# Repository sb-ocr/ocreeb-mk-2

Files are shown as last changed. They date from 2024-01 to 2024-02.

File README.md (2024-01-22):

# Ocreeb MK2: Modular Macro Keyboard System 

Watch the build video ↓

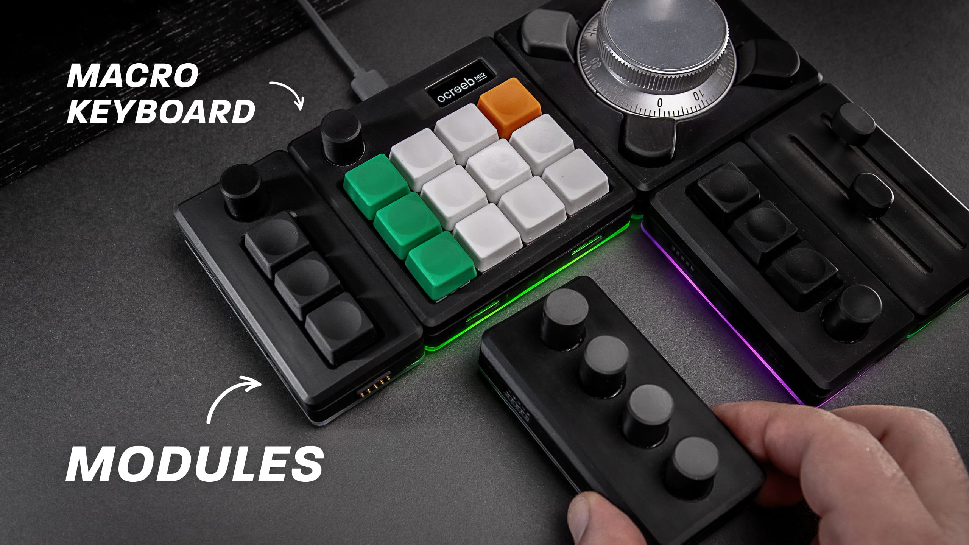
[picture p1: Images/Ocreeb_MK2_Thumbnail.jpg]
[](https://youtu.be/7DfexfHzT-w)

Ocreeb MK2 is the second iteration of my macropad project. This version features the XIAO RP2040, supports hotswap sockets for the macropad, a detachable switch plate, an OLED screen, and magnetic external modules running the Seesaw firmware.

As I mentioned in the video, there are still major performance issues when using multiple external modules. This is probably due to my implementation of the shared interrupt, and I will look into it. 
Nevertheless, I will supplement this repo with all the files in case you ever wish to use a part of this.

Build instructions → [Instructables](https://www.instructables.com/Modular-Macro-Keyboard-System-Ocreeb-MK2/)

[][cc-by-nc-sa]

[][cc-by-nc-sa]

[cc-by-nc-sa]: http://creativecommons.org/licenses/by-nc-sa/4.0/
[cc-by-nc-sa-image]: https://licensebuttons.net/l/by-nc-sa/4.0/88x31.png
[cc-by-nc-sa-shield]: https://img.shields.io/badge/License-CC%20BY--NC--SA%204.0-lightgrey.svg

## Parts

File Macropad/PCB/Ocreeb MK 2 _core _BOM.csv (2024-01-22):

Qty | Parts | Device | Value | Package | MP | Digikey | Type | Description | Link
1 | U1 | XIAO RP2040 |  |  | 102010428 | 1597-102010428-ND | SMD | RP2040 XIAO RP2040 - ARM® Cortex®-M0+ MCU 32-Bit
6 | C1, C2, C3, C4, C5, C6 | C_CHIP-0603(1608-METRIC) | 0.1uF | CAPC1608X85 | C0603C104M5RAC7867 | 399-C0603C104M5RAC7867CT-ND | SMD | 0.1 µF ±20% 50V Ceramic Capacitor X7R 0603 (1608 Metric)
5 | R1, R2, R3, R4, R5 | R-US_CHIP-0603(1608-METRIC) | 10K | RESC1608X60 | RMCF0603FT10K0 | RMCF0603FT10K0CT-ND | SMD | 10 kOhms ±1% 0.1W, 1/10W Chip Resistor 0603 (1608 Metric)
1 | F1 | PPTC_0.75A | 6V/0.75A | 1206 (3216 Metric) | PTS12066V075 | 283-PTS12066V075CT-ND | SMD | Polymeric PTC Resettable Fuse 6V 750 mA Ih Surface Mount 1206 (3216 Metric), Concave
2 | Q1, Q2 | BSS138 | BSS138 | SOT-23-3 | BSS138 | 4530-BSS138CT-ND | SMD | N-Channel 50 V 220mA (Ta) 350mW (Ta) Surface Mount SOT-23
4 | RN1, RN2, RN3, RN4 | CAY16-103J4LF | CAY16-103J4LF | 1206 (3216 Metric) | CAY16-103J4LF | CAY16-103J4LFCT-ND | SMD | 10k Ohm ±5% 62.5mW Power Per Element Isolated 4 Resistor Network/Array ±200ppm/°C 1206 (3216 Metric), Convex, Long Side Terminals
1 | U5 | SN74AHCT1G126DBVR | SN74AHCT1G126DBVR | SOT-23-5 | SN74AHCT1G126DBVR | 296-4710-1-ND | SMD | Buffer, Non-Inverting 1 Element 1 Bit per Element 3-State Output SOT-23-5
2 | U2, U3 | SN74HC165DBR16-TSSOP | SN74HC165DBR16-TSSOP | 16-SSOP | SN74HC165DBR | 296-23151-1-ND | SMD | Shift Shift Register 1 Element 8 Bit 16-SSOP
1 | U4 | TCA4307DGKR | TCA4307DGKR | 8-VSSOP | TCA4307DGKR | 296-TCA4307DGKRCT-ND | SMD | Hot Swap Controller 1 Channel General Purpose 8-VSSOP
4 | LED1, LED2, LED3, LED4 | WS2812B | WS2812B | WS2812B | COM-16347 | 1568-COM-16347CT-ND | SMD | Addressable Lighting - LED Serial NRZ (Shift Register) Red, Green, Blue (RGB)
1 | ENC | PEC11R-4215F-S0024 | PEC11R-4215F-S0024 | PEC11R-4215F-S0024 | PEC11R-4215F-S0024 | PEC11R-4215F-S0024-ND | TH | Rotary Encoder Mechanical 24 Quadrature (Incremental) Vertical
12 | S1, S2, S3, S4, S5, S6, S7, S8, S9, S10, S11, S12 | MX HOT SWAP SOCKETS |  | 20 Pack | 4958 | 1528-4958-ND | SMD | Kailh MX Hotswap Sockets
12 | S1, S2, S3, S4, S5, S6, S7, S8, S9, S10, S11, S12 | MX SWITCHES |  | 12 Pack | 5122 | 1528-5122-ND | TH | MX-Compatible Mechanical Keys
1 | OLED | OLED MODULE |  | 3 pcs |  |  | MOD | 0.91 inch OLED Display Module SSD1306 I2C 128x32 | https://geni.us/Jc6463D
6 | CONNECTOR | 5PIN_EDGE_LANDING |  | 5 pcs |  |  | SUB | Custom landing pads PCB | https://github.com/sb-ocr/ocreeb-mk-2/tree/main/Connector/PCB/Gerbers
4 | SCR | M2 x 6mm |  | Assorted Lengths Kit |  |  | SCR | M2 Self-Tapping Screws | https://geni.us/OKq551
3 | SCR | M2 x 12mm |  | Assorted Lengths Kit |  |  | SCR | M2 Self-Tapping Screws | https://geni.us/OKq551
4 | SCR | M2 x 16mm |  | Assorted Lengths Kit |  |  | SCR | M2 Self-Tapping Screws | https://geni.us/OKq551
12 | MAG | 6 x 3mm |  | 40 pcs |  |  | MAG | Small Neodymium Magnets | https://geni.us/X7I9
4 | ADH | 6 x 2 mm |  | Assorted Kit |  |  | ADH | Adhesive Bumper Pads Self Stick | https://geni.us/v9UIrL

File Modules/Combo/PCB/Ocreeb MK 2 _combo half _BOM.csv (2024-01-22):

Qty | Parts | Value | Device | Package | MP | Digikey | Type | Description | Link
3 | C1, C2, C3 | 0.1uF | C_CHIP-0603(1608-METRIC) | CAPC1608X85 | C0603C104M5RAC7867 | 399-C0603C104M5RAC7867CT-ND | SMD | 0.1 µF ±20% 50V Ceramic Capacitor X7R 0603 (1608 Metric)
2 | R1, R2 | 10K | R-US_CHIP-0603(1608-METRIC) | RESC1608X60 | RMCF0603FT10K0 | RMCF0603FT10K0CT-ND | SMD | 10 kOhms ±1% 0.1W, 1/10W Chip Resistor 0603 (1608 Metric)
1 | C4 | 10uF | C_CHIP-0805(2012-METRIC) | CAPC2012X110 | CL21A106KOQNNNE | 1276-1096-1-ND | SMD | 10 µF ±10% 16V Ceramic Capacitor X5R 0805 (2012 Metric)
1 | U1 | ATTINY816 | ATTINY816 | 20-SOIC | ATTINY816-SNR | ATTINY816-SNRCT-ND | SMD | AVR tinyAVR™ 1, Functional Safety (FuSa) Microcontroller IC 8-Bit 20MHz 8KB (8K x 8) FLASH 20-SOIC
1 | RN4 | CAY16-103J4LF | CAY16-103J4LF | 1206 (3216 Metric) | CAY16-103J4LF | CAY16-103J4LFCT-ND | SMD | 10k Ohm ±5% 62.5mW Power Per Element Isolated 4 Resistor Network/Array ±200ppm/°C 1206 (3216 Metric), Convex, Long Side Terminals
2 | LED1, LED2 | WS2812B | WS2812B | WS2812B | COM-16347 | 1568-COM-16347CT-ND | SMD | Addressable Lighting - LED Serial NRZ (Shift Register) Red, Green, Blue (RGB)
1 | ENC | PEC11R-4215F-S0024 | PEC11R-4215F-S0024 | PEC11R-4215F-S0024 | PEC11R-4215F-S0024 | PEC11R-4215F-S0024-ND | TH | Rotary Encoder Mechanical 24 Quadrature (Incremental) Vertical
3 | S1, S2, S3 |  |  | 12 Pack | 5122 | 1528-5122-ND | TH | MX-Compatible Mechanical Keys
5 | CONNECTOR |  | POGO_PIN |  | 0906-0-15-20-76-14-11-0 | ED8180-ND | TH | Contact Spring Through Hole
1 | CONNECTOR |  | 5PIN_EDGE_CONNECTOR |  |  |  | SUB | Custom connector PCB | https://github.com/sb-ocr/ocreeb-mk-2/tree/main/Connector/PCB/Gerbers
5 | CONNECTOR |  | 5PIN_EDGE_LANDING |  |  |  | SUB | Custom landing pads PCB | https://github.com/sb-ocr/ocreeb-mk-2/tree/main/Connector/PCB/Gerbers
2 | SCR | M2 x 12mm |  | Assorted Lengths Kit |  |  | SCR | M2 Self-Tapping Screws | https://geni.us/OKq551
4 | SCR | M2 x 16mm |  | Assorted Lengths Kit |  |  | SCR | M2 Self-Tapping Screws | https://geni.us/OKq551
12 | MAG | 6 x 3mm |  | 40 pcs |  |  | MAG | Small Neodymium Magnets | https://geni.us/X7I9
4 | ADH | 6 x 2 mm |  | Assorted Kit |  |  | ADH | Adhesive Bumper Pads Self Stick | https://geni.us/v9UIrL

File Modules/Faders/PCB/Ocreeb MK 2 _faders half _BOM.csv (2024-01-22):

Qty | Parts | Value | Device | Package | MP | Digikey | Type | Description | Link
3 | C1, C2, C3 | 0.1uF | C_CHIP-0603(1608-METRIC) | CAPC1608X85 | C0603C104M5RAC7867 | 399-C0603C104M5RAC7867CT-ND |  | 0.1 µF ±20% 50V Ceramic Capacitor X7R 0603 (1608 Metric)
1 | C4 | 10uF | C_CHIP-0805(2012-METRIC) | CAPC2012X110 | CL21A106KOQNNNE | 1276-1096-1-ND |  | 10 µF ±10% 16V Ceramic Capacitor X5R 0805 (2012 Metric)
1 | U1 | ATTINY816 | ATTINY816 | 20-SOIC | ATTINY816-SNR | ATTINY816-SNRCT-ND |  | AVR tinyAVR™ 1, Functional Safety (FuSa) Microcontroller IC 8-Bit 20MHz 8KB (8K x 8) FLASH 20-SOIC
2 | RN1, RN2 | CAY16-103J4LF | CAY16-103J4LF | 1206 (3216 Metric) | CAY16-103J4LF | CAY16-103J4LFCT-ND |  | 10k Ohm ±5% 62.5mW Power Per Element Isolated 4 Resistor Network/Array ±200ppm/°C 1206 (3216 Metric), Convex, Long Side Terminals
2 | LED1, LED2 | WS2812B | WS2812B | WS2812B | COM-16347 | 1568-COM-16347CT-ND |  | Addressable Lighting - LED Serial NRZ (Shift Register) Red, Green, Blue (RGB)
2 | POT1, POT2 | PTA6043-2015DP-B103 | PTA6043-2015DP-B103 | PTA6043-2015DP-B103 | PTA6043-2015DPB103 | PTA6043-2015DPB103-ND |  | 10 kOhms 0.25W, 1/4W Through Hole Slide Potentiometer Top Adjustment Type
5 | CONNECTOR |  | POGO_PIN |  | 0906-0-15-20-76-14-11-0 | ED8180-ND |  | Contact Spring Through Hole
1 | CONNECTOR |  | 5PIN_EDGE_CONNECTOR |  |  |  | SUB | Custom connector PCB | https://github.com/sb-ocr/ocreeb-mk-2/tree/main/Connector/PCB/Gerbers
5 | CONNECTOR |  | 5PIN_EDGE_LANDING |  |  |  | SUB | Custom landing pads PCB | https://github.com/sb-ocr/ocreeb-mk-2/tree/main/Connector/PCB/Gerbers
2 | SCR | M2 x 12mm |  | Assorted Lengths Kit |  |  | SCR | M2 Self-Tapping Screws | https://geni.us/OKq551
4 | SCR | M2 x 16mm |  | Assorted Lengths Kit |  |  | SCR | M2 Self-Tapping Screws | https://geni.us/OKq551
12 | MAG | 6 x 3mm |  | 40 pcs |  |  | MAG | Small Neodymium Magnets | https://geni.us/X7I9
4 | ADH | 6 x 2 mm |  | Assorted Kit |  |  | ADH | Adhesive Bumper Pads Self Stick | https://geni.us/v9UIrL

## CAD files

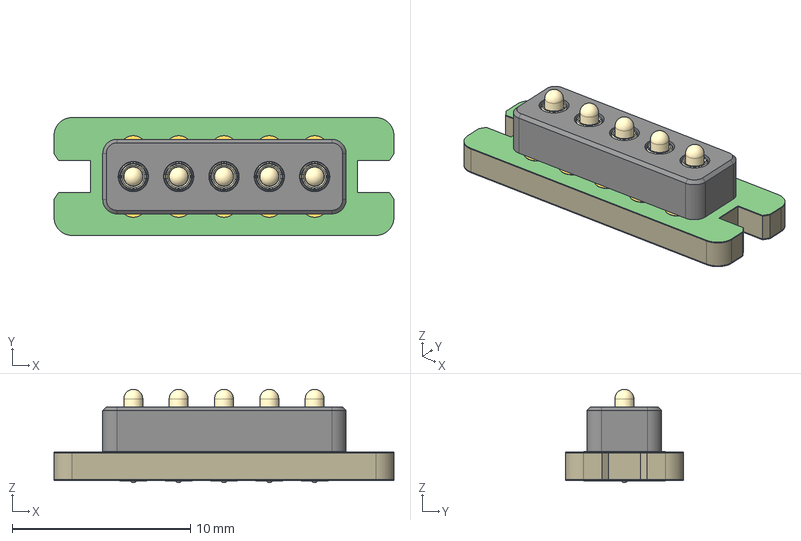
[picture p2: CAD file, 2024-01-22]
Connector/CAD/Ocreeb MK2 _5_pin_connect.step
19.1 x 6.60 x 5.23 mm
Board
0906-0-15-20-76-14-11-0--3DModel-STEP-56544 v1 x 5
Pogo Connector Guide v1
1-copper
16-copper
1-soldermask
16-soldermask

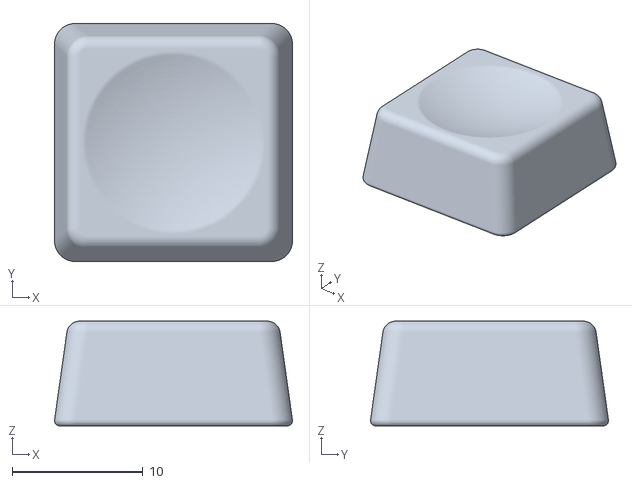
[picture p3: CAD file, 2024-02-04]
Macropad/CAD/STLs/Ocreeb_keycap.stl
18.2 x 18.2 x 8.00

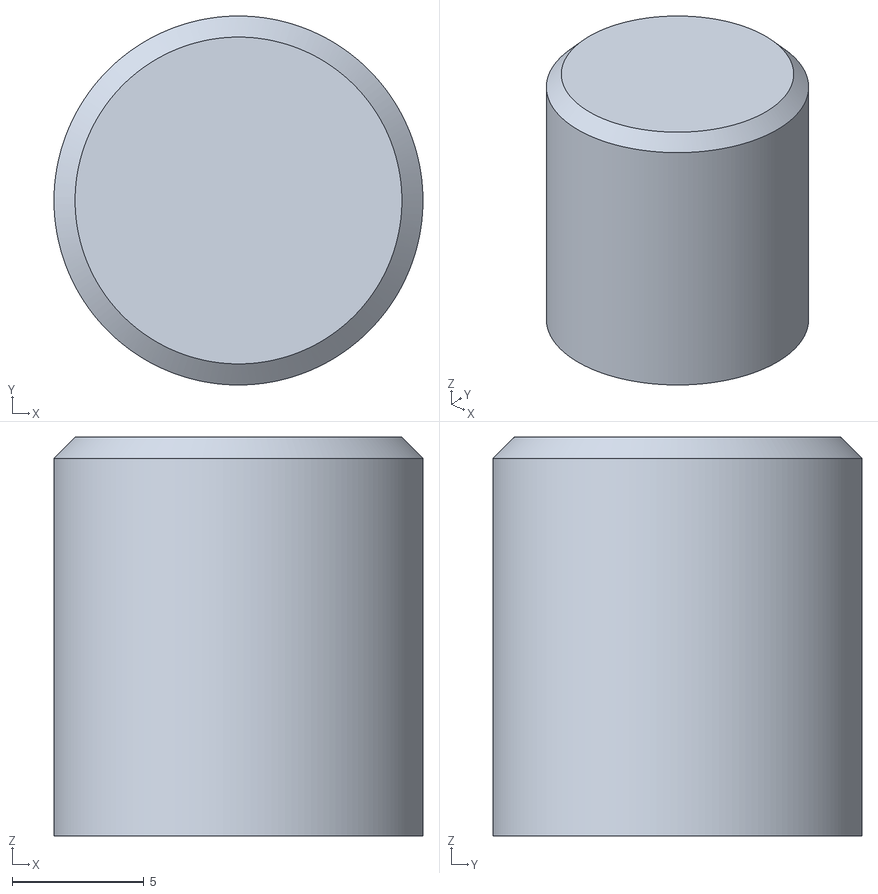
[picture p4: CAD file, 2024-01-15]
Modules/Dials/CAD/STLs/Ocreeb_dial_knob.stl
14.0 x 14.0 x 15.1

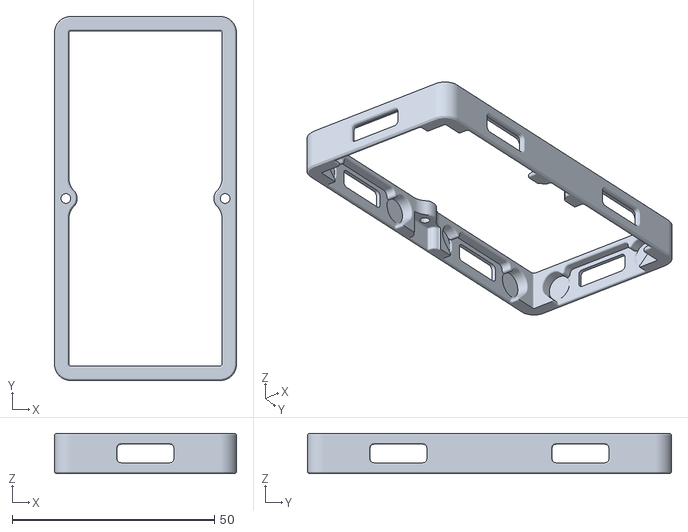
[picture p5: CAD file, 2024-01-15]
Modules/Faders/CAD/STLs/Ocreeb_module_half_middle.stl
45.0 x 90.0 x 10.0

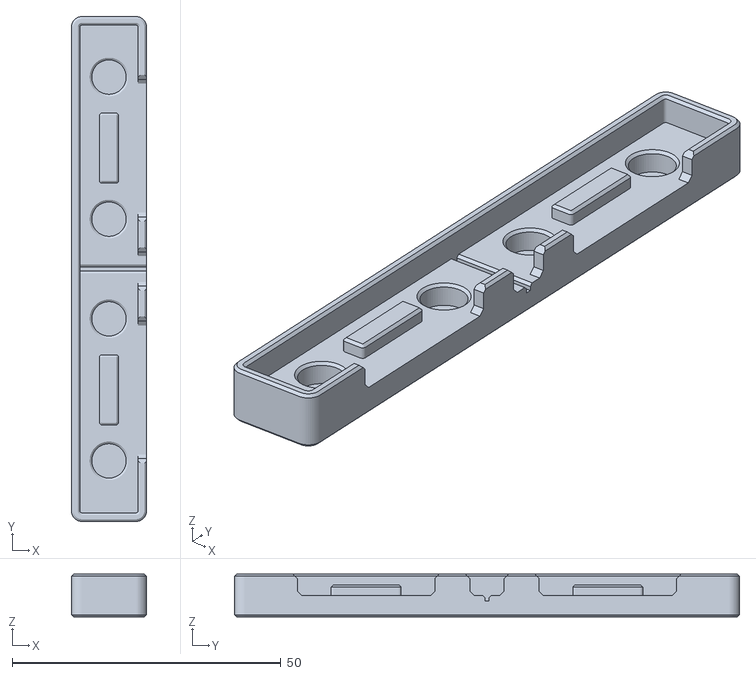
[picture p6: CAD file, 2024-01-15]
Modules/Utils/connector_magnet_jig.stl
14.0 x 94.0 x 8.00

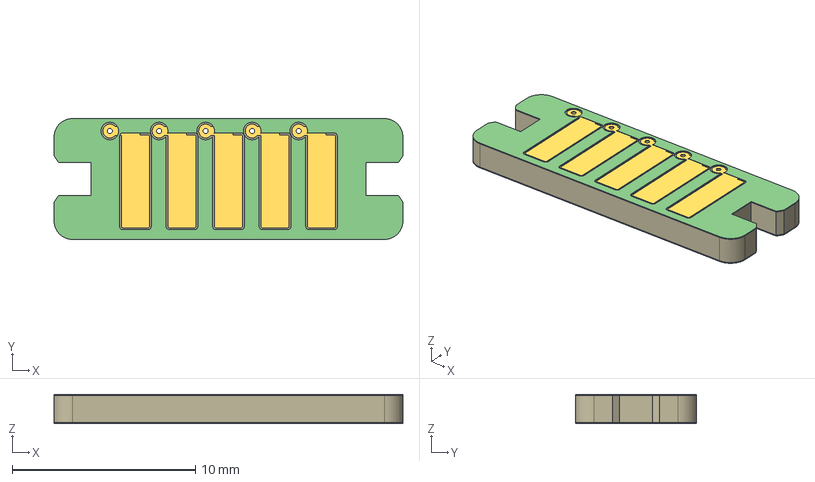
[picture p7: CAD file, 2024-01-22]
Connector/CAD/Ocreeb MK2 _5_pin_landing.step
19.1 x 6.60 x 1.60 mm
Board
1-copper
16-copper
1-soldermask
16-soldermask

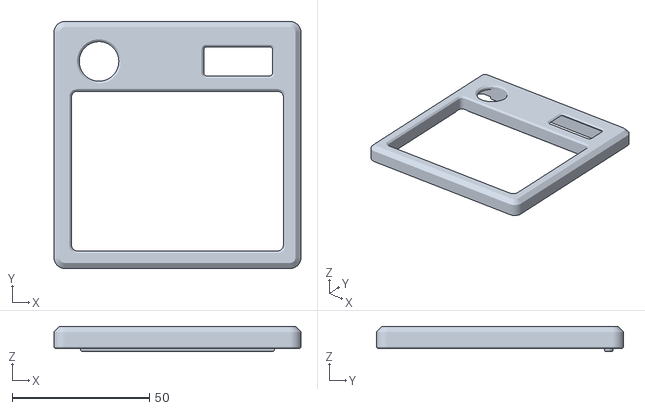
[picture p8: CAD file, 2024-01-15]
Macropad/CAD/STLs/Ocreeb_core_top.stl
90.0 x 90.0 x 9.20

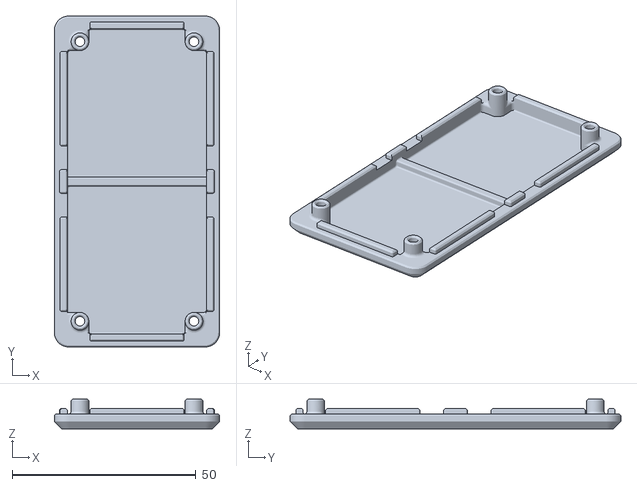
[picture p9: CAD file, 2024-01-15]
Modules/Combo/CAD/STLs/Ocreeb_module_half_bottom.stl
45.0 x 90.0 x 8.05

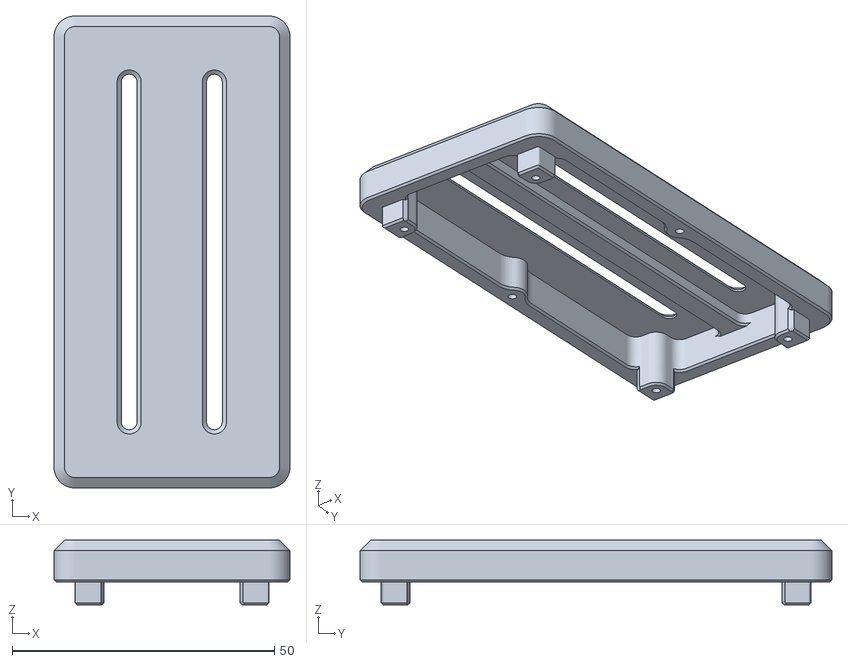
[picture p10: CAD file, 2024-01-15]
Modules/Faders/CAD/STLs/Ocreeb_faders_half_top.stl
45.0 x 90.0 x 12.3

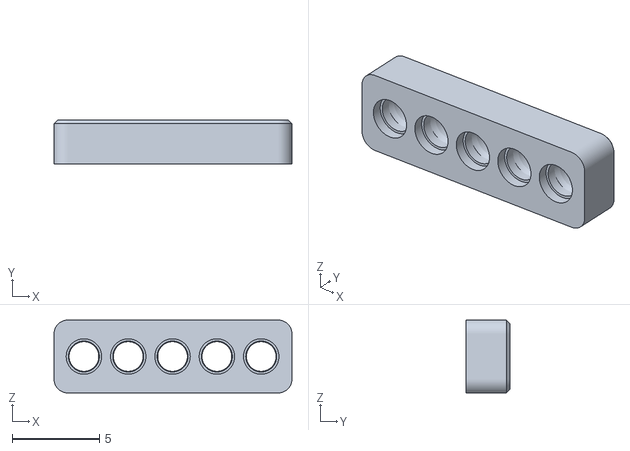
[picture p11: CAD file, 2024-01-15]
Connector/CAD/Ocreeb_connector_shroud.stl
13.6 x 2.50 x 4.18

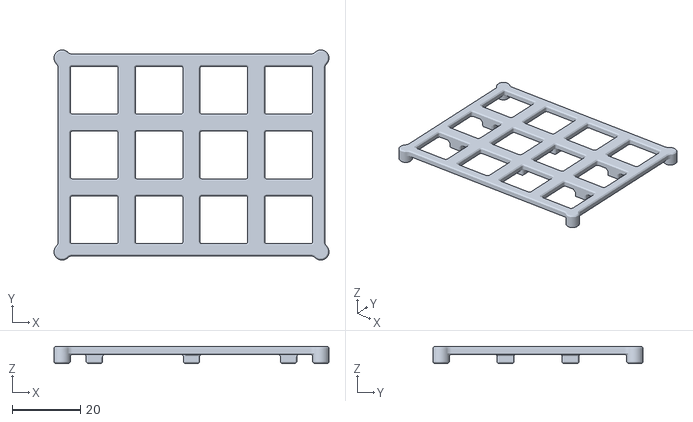
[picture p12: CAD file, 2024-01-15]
Macropad/CAD/STLs/Ocreeb_core_switch_plate.stl
80.8 x 61.7 x 5.00

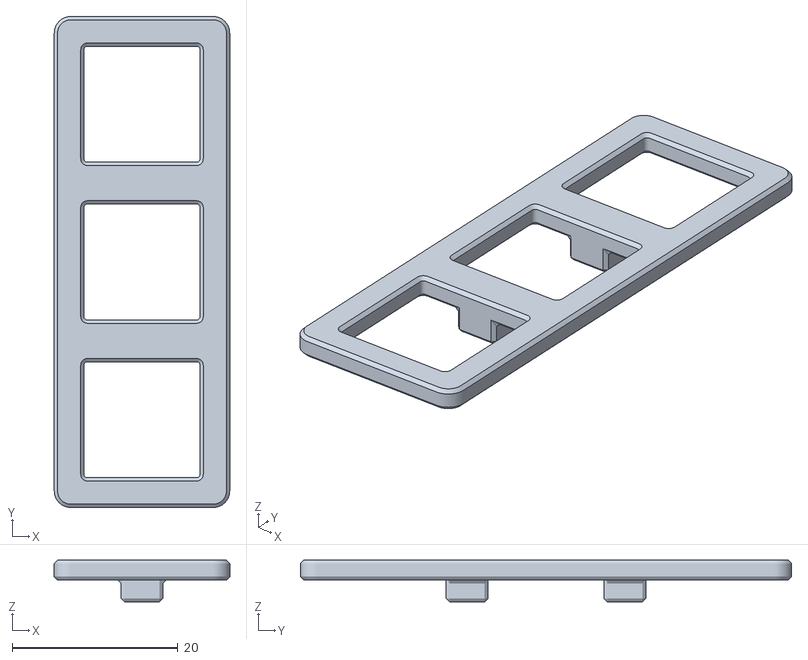
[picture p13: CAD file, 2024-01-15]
Modules/Combo/CAD/STLs/Ocreeb_combo_half_switch_plate.stl
21.2 x 59.3 x 5.03

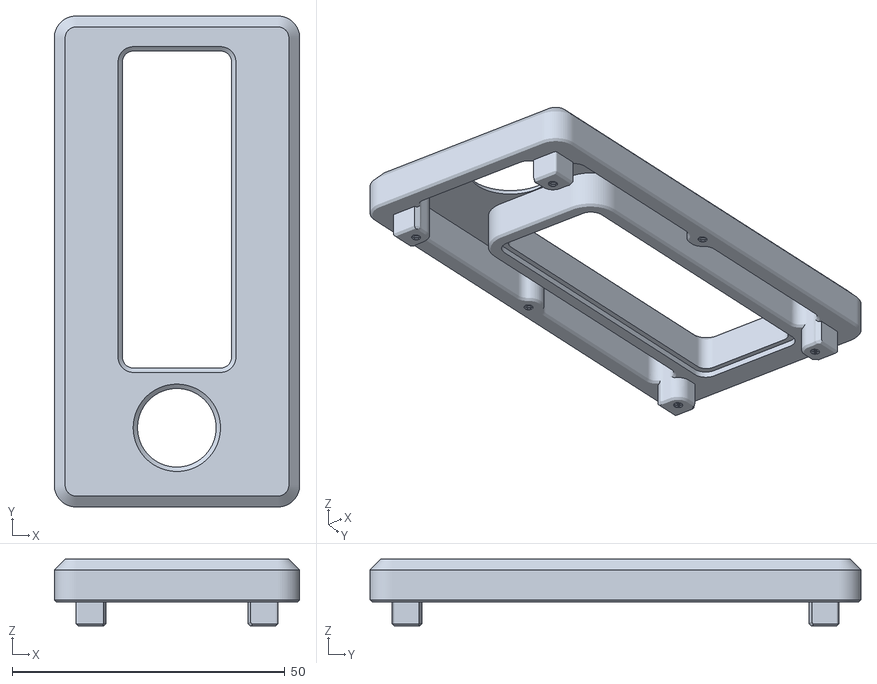
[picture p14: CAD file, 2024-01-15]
Modules/Combo/CAD/STLs/Ocreeb_combo_half_top.stl
45.0 x 90.0 x 12.3

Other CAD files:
Macropad/CAD/STLs/Ocreeb_core_bottom.stl
Macropad/CAD/STLs/Ocreeb_core_middle.stl
Modules/Dials/CAD/STLs/Ocreed_dials_half_top.stl
Modules/Faders/CAD/STLs/Ocreeb_fader_knob.stl

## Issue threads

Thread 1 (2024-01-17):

decode module nr in pulse count fast

crbyxwpzfl, 2024-01-17:
hi this is so cool of you @sb-ocr! ok disclaimer im writing this in my brake rn I will revise this later the example likely is faulty currently

#### tldr.
perhaps this helps to decode the module nr. in the interrupt pulses fast enough.

```py
import board
import array
import adafruit_pioasm
import rp2pio

count prof = adafruit_pioasm.assemble( """
.program counter

mov ~y y          ; initial prep for addpulse

reset:            ; this block initiates grace time and waits till pin is low
set x 11111           ; set retry counter or grace period max 5bit
wait 0 pin 0          ; wait till pin is low

findedge:         ; this tries to find pulse or exits
jmp pin addpulse      ; when pin high add one to pulse count
jmp x— exit           ; else exit when grace period is zero
jmp findedge          ; else retry

addpulse:         ; this adds one to pulse counter
jmp y—                ; adds one since y is inversed in exit
jmp reset             ; reset grace period and test for next pulse

exit:             ; this writes pulse count to isr
jmp y! reset          ; when y zero alias no pulses detected reset
mov ~y y              ; inverses y/pulse count so isr is filled with real count
mov isr y             ; depletes y to zero and fills isr
mov ~y y              ; inverses y to prep it for addpulse
push noblock          ; push isr and do not wait for empty tx fifo
"""

countpio = rp2pio.StateMachine(
    program    = countprog,
    frequency  = 0,  # 125MHz pio clock speed
    jmp_pin    = board.A0,  # interrupt line pin
)

pulsecount = array.array( 'L', [32] )

while True:
    while countpio.in_waiting() < 1:  # wait until at least one count is available
        pass
    while countpio.in_waiting() > 0:  # read all words in fifo
        countpio.readinto(pulsecount)  # read from rx fifo
        print(pulsecount[0])
    countpio.clear_rxfifo()  # reset rx fifo to make room for new counts

```

#### limits since one instruction takes 8ns at 125MHz
11111bin/32dec *8ns = 256ns is the grace period until pulse count is reset
2 *8ns = 16ns is the minimum high time for one pulse
i dont know the minimum low time of a pulse but perhaps 8ns duno
assumes a default low state of the interrupt line
tx fifo contains up to 4 pulse counts then counts are lost
dwell time for one pulse count until the next is 7 *8ns = 56ns

#### more info
this is circuit python. with [rp2pio](https://docs.circuitpython.org/en/latest/shared-bindings/rp2pio/index.html) and [adafruit_pioasm](https://docs.circuitpython.org/projects/pioasm/en/latest/) libraries from [adafruit](https://learn.adafruit.com/intro-to-rp2040-pio-with-circuitpython/overview) you can init a [pio of the rp2040](https://datasheets.raspberrypi.com/rp2040/rp2040-datasheet.pdf#page320) to count pulses until no pulse is detected for 256ns (but this is adjustable). After one count the pio needs 56ns then it’s ready to count again (perhaps this can be helped by using two pios). So no simultaneous inputs are possible like this. I think. anyways feel free to close this at anytime this is just a thought

<details><summary>or perhaps encode the module nr. in pulse width </summary>

this is to read pulse length you need rp2pio and adafruit_pioasm libraries.  [source of the pio code](https://github.com/GitJer/PwmIn/blob/2cf703178b6aa891e5d781d75ee039905cae52ad/PwmIn.pio)
```py
import board
import adafruit_pioasm
import rp2pio

pwminprog = adafruit_pioasm.assemble( """
.program PwmIn

; algorithm:

; loop:
;    reset the 'timer'
;    loop:
;       decrement timer
;       test for falling edge
;    record timer value as pulse width (actually, (0xFFFFFFFF - x)*2/125MHz is the pulse width)
;    loop:
;       test for rising edge
;       decrement timer
;    record the timer value as period (actually, (0xFFFFFFFF - x)*2/125MHz is the period)

.wrap_target
    mov x ~NULL         ; start with the value 0xFFFFFFFF

timer:
    jmp x-- test        ; count down
    jmp timerstop       ; timer has reached 0, stop count down
test:
    jmp pin timer       ; test if the pin is still 1, if so, continue counting down
timerstop:              ; pulse is over (or timer has reached 0)
    mov ISR x           ; move the value in x to the ISR: the pulsewidth (0xFFFFFFFF-pulsewidth)
    push noblock        ; push the ISR into the RX FIFO

timer2:
    jmp pin timerstop2  ; if the pin has become 1, the period is over, stop count down
    jmp x-- timer2      ; if not: count down
timerstop2:
    mov ISR x           ; move the value in x to the ISR: the period (0xFFFFFFFF-period)
    push noblock        ; push the ISR into the RX FIFO

.wrap
"""

pwminpio = rp2pio.StateMachine(
    program          = pwminprog,
    frequency       = 0,
    jmp_pin           = board.A0,
    in_shift_right  = False,
)

lowtime = array.array( 'L', [32] )
hightime = array.array( 'L', [32] )

while True:
    pwminpio.clear_rxfifo()
    while pwminpio.in_waiting() < 2:
        pass
    pwminpio.readinto(hightime)
    print(hightime[0])
    pwminpio.readinto(lowtime)
    print(hightime[0])

```

</details>

#### even more info
im not too good at programming and quite new to this in general. anyways
I saw your video and your issue with missing inputs due to pulling inefficiencies. you proposed to encode the module nr. in the interrupt pulses. I recently tried to read a pwm signal of a phillips hue lamp and had the same issue with circuit python being to slow. I solved the issue by reading the signal via a pio of the rp2040. hope this is relevant to you since it is all circuit python it shloud be possible to integrate without a rewrite in c or so

sb-ocr, 2024-01-18:
Hey, this is amazing! thank you for taking the time to detail your suggestion.
I will definitely try it when I get to working on that issue.

Closed 2024-01-18.

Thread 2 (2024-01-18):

License?

calebcoverdale, 2024-01-18:
Hey there,

Just noticed your project doesn’t have a license file. Thought I’d mention that adding a license could be really beneficial, especially for a cool project like this. A license helps protect your work from being copied or misused. It also makes it clear how others can use, modify, or distribute your design.

I wasn't stepping on your work. It's truly what I've been looking to play with. I have lots of boards, sensors, but this finally pulls it altogether.

Thanks so much for your work on this!

I'm printing the files as we speak so I can start to tinker!

DemonChicken1111, 2024-01-18:
I was also wondering about this! Thanks for putting the question out!

sb-ocr, 2024-01-18:
Hey, thanks for letting me know. I usually do, but I forgot when I was frantically uploading the repo the other day. I'm still working on the build instructions, and I will update and clean up the project in the upcoming days. In the meantime, I have added the licenses for anyone wanting to tinker with this.

Thanks again for bringing this to my attention!

Closed 2024-01-18.

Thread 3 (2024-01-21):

CAD files

Rom4ik-glitch, 2024-01-21:
Hi. Can you please update CAD/STL sections with .step files? i would like to make a my own macropads and modules based on your design

XEJK, 2024-01-22:
I would also be very interested in this.

sb-ocr, 2024-01-22:
Uploaded Step files. Lmk if you need anything else.

Rom4ik-glitch, 2024-01-22:
Also, i know, am asking a lot, but could you please upload schematics of modules in pdf? i want to see for any ability to improve interface perfomance, for example, by implementing CAN interface, ore smth like that, so need to see whats inside the box :)

sb-ocr, 2024-02-04:
@Rom4ik-glitch Done! I uploaded the PDFs and files if you want to change them in Eagle or Fusion

Closed 2024-01-22.

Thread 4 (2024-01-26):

Keycap CAD files

DemonChicken1111, 2024-01-26:
Hey! Noticed that the keycap STL is linked and listed in the instructables article, however it is nowhere to be found within the repo

sb-ocr, 2024-02-04:
Hi, I added it to the Macropad and combo module. Thanks for letting me know.

Closed 2024-02-04.

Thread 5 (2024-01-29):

Core and modules schematic files

Art3mis0940, 2024-01-29:
Hey! Can I ask you to attach schematic files of the boards for the Core and Modules, as was the case for the first version of the macropad?

magicfr, 2024-01-30:
Hi, Great job ... I will also be very interrested in the schematic files for the board. Could you share with us ?

sb-ocr, 2024-02-04:
Hey, I shared the Schematics and board files (Eagle 9.x / Fusion). I included PDFs as well incase you just want to peak

Closed 2024-02-04.

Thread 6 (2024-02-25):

Cannot get main macropad module to type

DemonChicken1111, 2024-02-25:
Hey! I have currently finished building the main macro-pad module. I have put the firmware code on the board, and I have checked my soldering a few times now. I cannot get the RGB to light up (The OLED works fine), and the board is constantly inputting strokes into my computer. I am not sure what is causing the issue. Here is my testing keymap in main.py:

`keyboard.keymap = [
    [
        KC.A,     KC.B,      KC.C,      KC.D,
        KC.E,     KC.F,      KC.G,      KC.H,
        KC.I,     KC.J,      KC.K,      KC.L,
    ]   # Layer 1
]`

Here is my output in a random text editor when this is saved to the board: (Note I am trying to push buttons, hold buttons etc, to try and get this to stop, which is where the new/random other letters start appearing)

`ddddddddddddddddddddddddddddddddddddddddddddddddddddddddddddddddddddddddddddddddddddddddddddddddddddddddddddddddddddddddddddddddddddddddddddddddddddddddddddddddddddddddddddddddddddddddddddddddddddddddddddddddddddddddddddddddddddddddddddddddddddddddddddddddddddddddddddddddddddddddddddddddddddddddddddddddddddddddddddddddddddddddddddddddddddddddddddddddddddddddddddddddddddddddddddddddddddddddddddddddddddddddddddddddddddddddddddddddddddddddddddddddddddddddddddiddjdklefdghlghbeaddlfcdgaddjkldefghdadibcddgaddjklefgdhadibdcdddddddddddddddddddddddddddddddddddddddddddddddddddddddddddddddddddddddddddddddddddddddddddddddddddddddddddddddddddddddddddddddddddddddddddddddddddddddddddddddddddddddddddddddddddddddddddddddddddddgaijklefghadddddddddddddddlbcjijklefghaddddddddddlbcjijklefghaddddddddddddddddddddddddlbcgaklefghaijjjjjjjjjjjjjjjjjjjjjjjjjjjjjjjjjjjjjjjjjjjjjjjjjjjjjjjjjjjjjjjjjjjjjjjjjjjjjjjjjjjjjjjjjjjjjjjjjjjjjjjjjjjjjjjjjjjjjjjjjjjjjjjjjjjjjjjjjjjjjjjjjjjjjjjjjjjjjjjjjjjjjjjjjjjjjjjjjjjjjjjjjjjjjjjjjjjjjjjjjjjjjjjjjjjjjjjjjjjjjjjjjjjjjjjjjjjjjjjjjjjjjjjjjjjjjjjjjjjjjjjjjjjjjjjjjjjjjjjjjjjjjjjjjjjjjjjjjjjjjjjjjbcdiijklefghaddddddddddddddlbcjijklefghadlbcgaijklefghadddddddddddddddddddddddddddddlbcgaijklefghadlbcgaklefghaijjjjjjjjjjjjjjjjjjjjjjjjjjjabcdgjklefghaiabgijklefghadddddddddddddddddddddddddddddddlbcjijklefghaddddddddddddddddddddddddddddddddddlj`

And here is my soldering work:

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

I'm not sure if you have encountered this issue, however I would like to resolve this issue. If you need any more files, code snippets, or log files let me know.

-Demon

sb-ocr, 2024-02-25:
Hey, at first glance, it seems like a soldering issue. You appear to have a bridge in one of the shift registers, and this is also consistent with the behavior you are describing. I would look there first and probe all the pins against the switches to make sure they are soldered properly and not bridging. As I mentioned in the video, the footprint I chose for the shift registers was kind of tight and was a pain to solder properly.
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

The Neopixels are soldered backwards. The notch needs to align with the diagonal line on the silkscreen.
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
Best of luck!

DemonChicken1111, 2024-02-26:
Thank you for the clarification on the LED's. Don't know how I missed that diagonal mark on the silkscreen lol. The bridging was the cause of the issue. One of the shift registers was bridged underneath the visible part of the chip (which was mostly part of my confusion looking for the bridges). Reflowing it, taking it off, and fixing the bridge solved my issues. Thank you!

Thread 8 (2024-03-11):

Nice Work!

Attempt3035, 2024-03-11:
@sb-ocr You wouldn't believe it, I did a school Design & Tech major works on this concept a few years back, you've implemented pretty much everything I ideated right down to the custom pogo pin connectors, only I did a base mounting board design. Sharing some of my old files here as they might be of interest! Obviously it's not super technical as it had to fit within particular marking guidelines and cover particular topics, but I'm sure you'll enjoy the blender render promo video that looks remarkably like the one in your youtube vid! If you ever decide to do a version 3, I'd love to have a chat, I've got other projects on at the moment but still would love to make this a reality for the live production / DJ space! Love your work!

[MIDIFIER Design Folio.pdf](https://github.com/sb-ocr/ocreeb-mk-2/files/14556556/MIDIFIER.Design.Folio.pdf)

https://github.com/sb-ocr/ocreeb-mk-2/assets/118163872/76b48793-5354-4200-937b-a4abdcf1b80e

sb-ocr, 2024-03-19:
Nice! yeah it does look very similar! Good job and thanks for sharing.

Closed 2024-03-19.

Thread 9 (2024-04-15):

incompatible .mpy file / no pull up found on SDA or SCL; check your wiring

cristy972, 2024-04-15:
Hi,
First of all, great job with this project :D i really want to finish the build and use it.

I've solder the components on boad and uploaded the firmware.
When it starts up i get this error.
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

I've commented the ocreebModule import line and the lines where its used just to check if i can get anything running, but after i did that i've got this error :(
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

I've put the code on an empty XIAO RP2040 and i got the same error.
Im new in this hobby and i dont know if i need anything connected to that pinouts to run the code or not.

Here is my board.

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

cristy972, 2024-04-15:
i've found out that i had the SDA and SCL wires inverted on the display, i've fixed that but still got the problem :(

Closed 2024-05-07.

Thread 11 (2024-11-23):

Missing Precision Encoder Module files

androXdev, 2024-11-23:
I searched around and wasn't able to find the CNC rotary encoder(Silver Knob) pcb and cad files. Could you point me to the location where it is or upload them if you have skipped it by mistake?

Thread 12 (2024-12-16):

Adafruit CircuitPython version

jakejarrett, 2024-12-16:
Hey,

After about an hour of wrangling errors last night, I final l got this project running (but complaining about the missing screen).

One of the main issues is that between the time of this project releasing & now, adafruit has upgraded from v8.2.9 to v9 (and out of beta, more importantly).

Could we please add some documentation for which version of adafruit is required  (`Adafruit CircuitPython 8.2.9 on 2023-12-06; Seeeduino XIAO RP2040 with rp2040`) - I will also likely come back to this later this week when I finish my build &  submit an MR for documentation

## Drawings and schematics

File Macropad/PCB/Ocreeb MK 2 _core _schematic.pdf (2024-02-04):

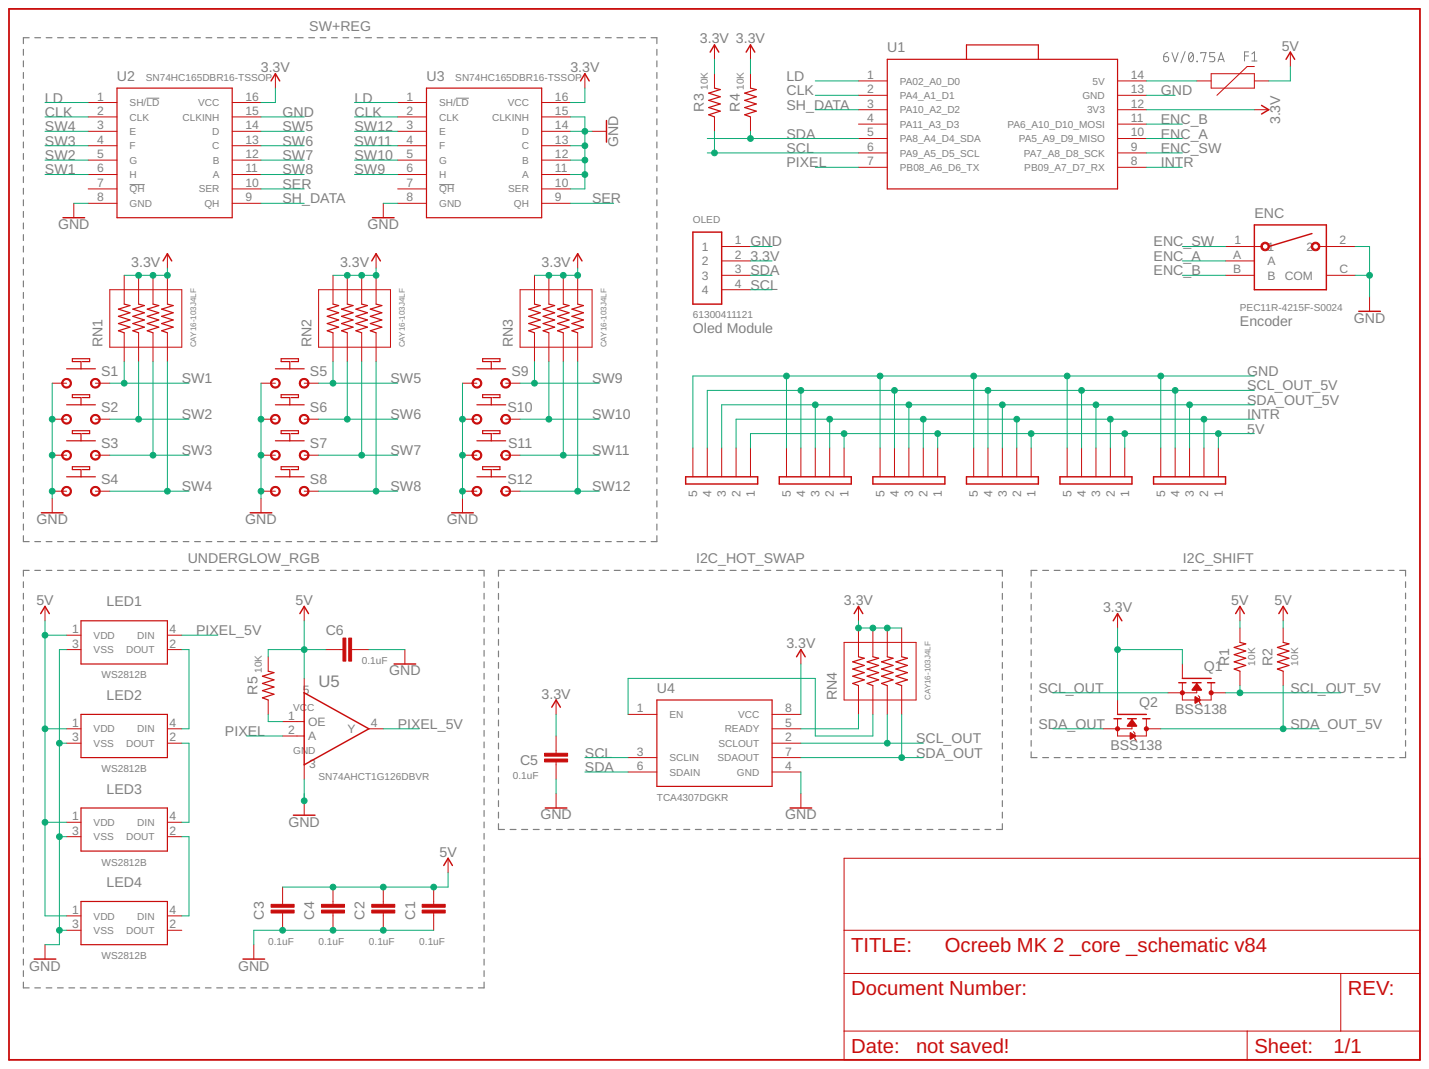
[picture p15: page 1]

Document Number: | REV:

Date: not saved! | Sheet: 1/1

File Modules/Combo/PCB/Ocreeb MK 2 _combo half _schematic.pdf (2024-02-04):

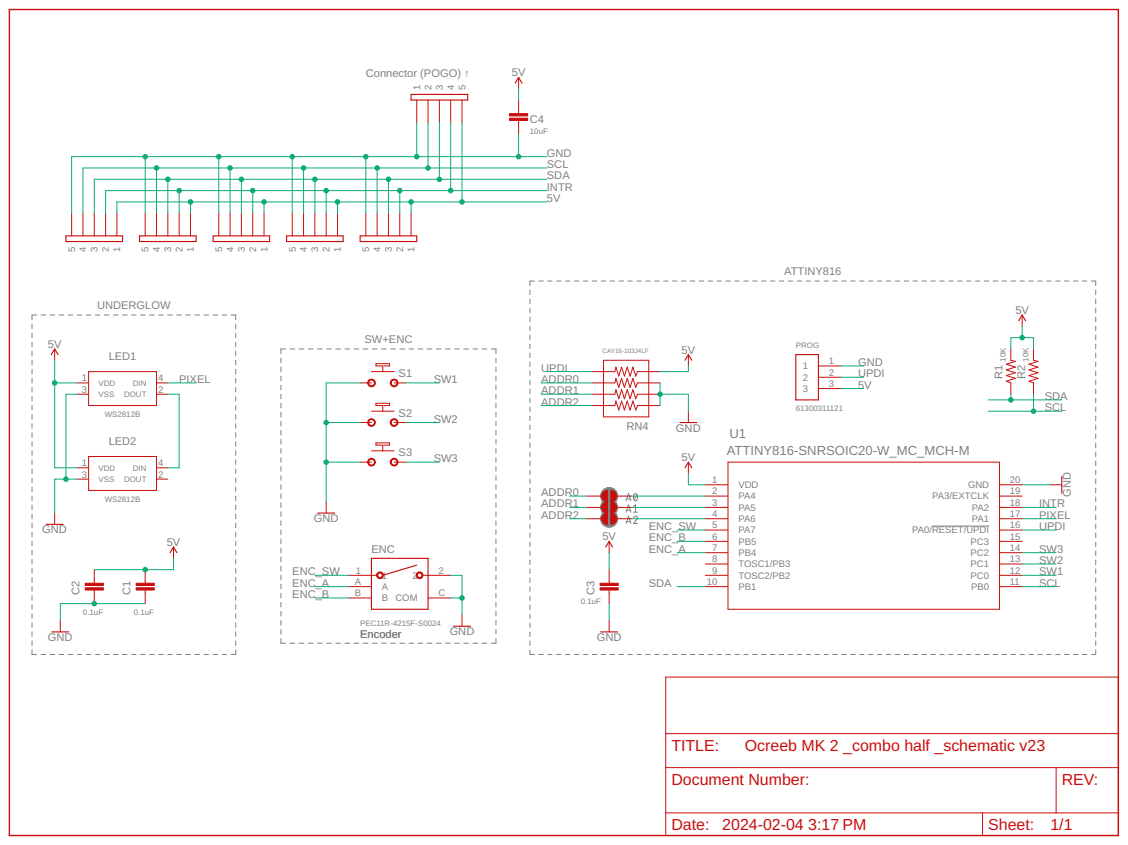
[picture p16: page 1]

Document Number: | REV:

Date: 2024-02-04 3:17 PM | Sheet: 1/1

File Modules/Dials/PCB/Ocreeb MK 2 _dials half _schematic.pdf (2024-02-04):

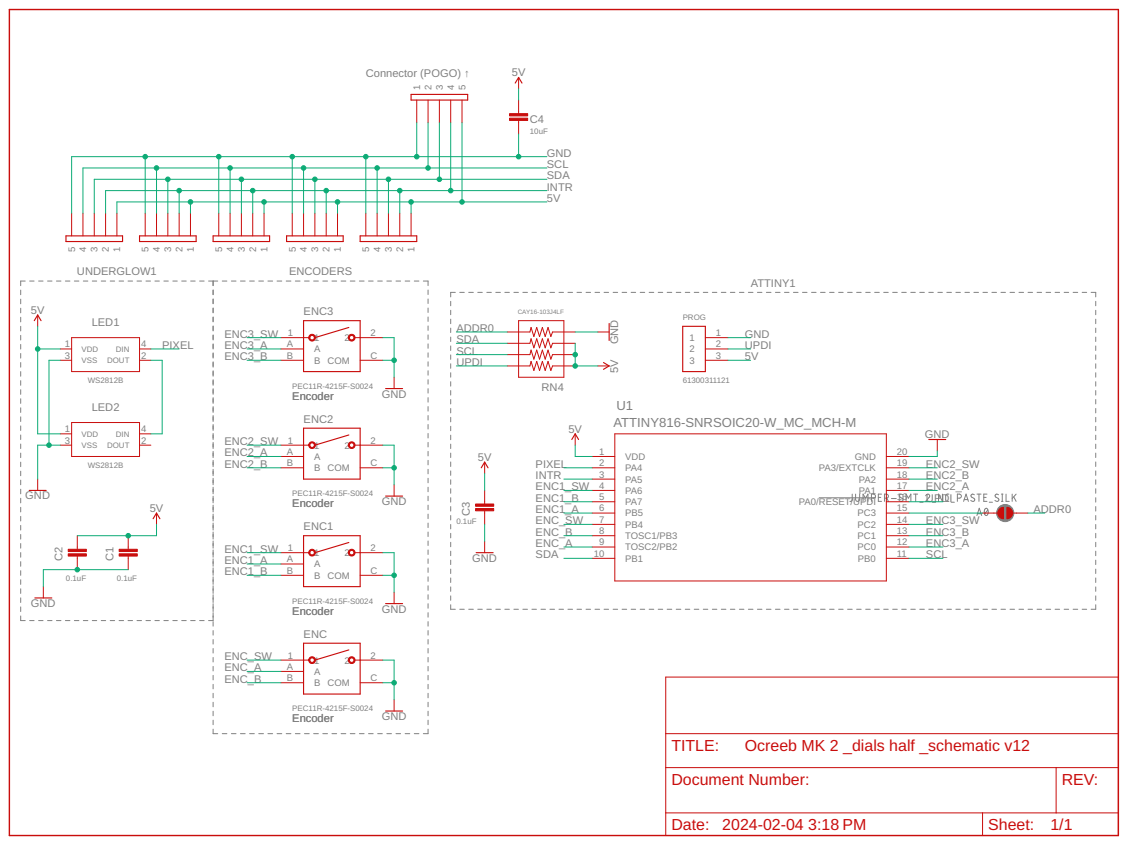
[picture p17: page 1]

Document Number: | REV:

Date: 2024-02-04 3:18 PM | Sheet: 1/1

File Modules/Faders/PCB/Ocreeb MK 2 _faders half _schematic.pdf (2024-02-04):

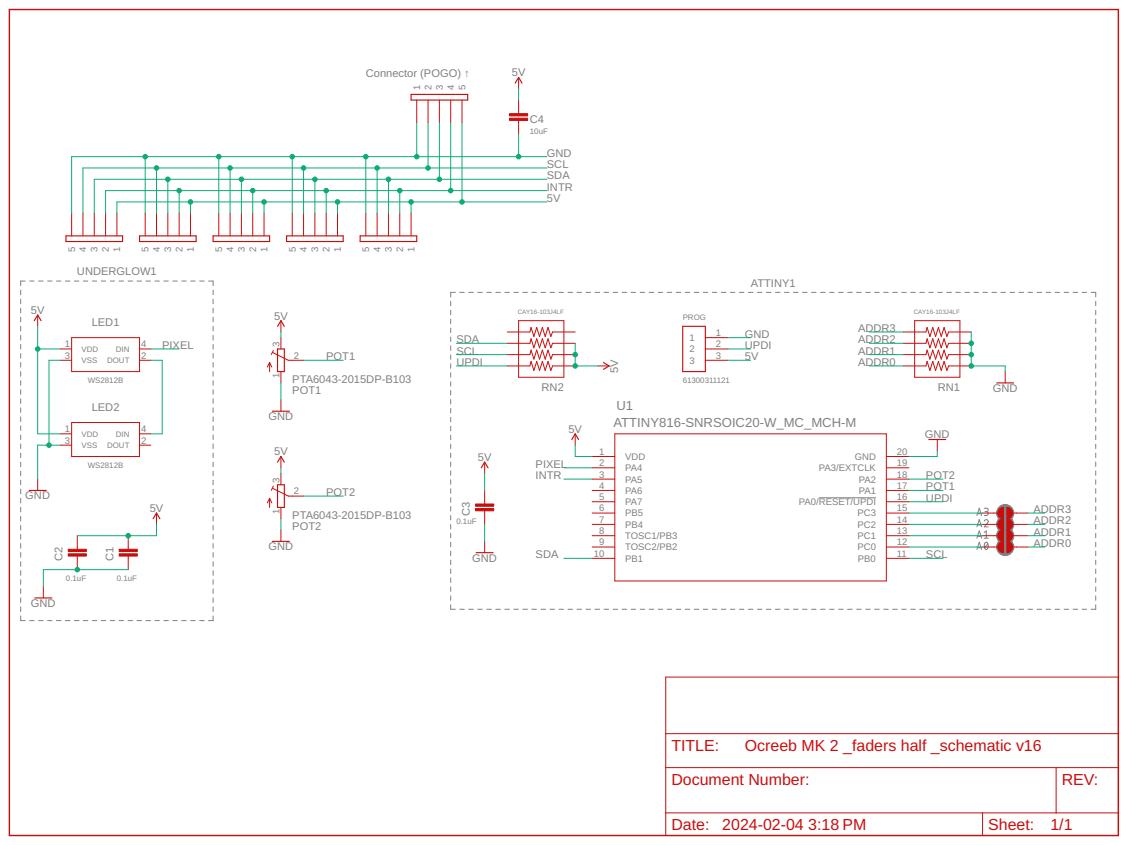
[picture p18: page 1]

Document Number: | REV:

Date: 2024-02-04 3:18 PM | Sheet: 1/1

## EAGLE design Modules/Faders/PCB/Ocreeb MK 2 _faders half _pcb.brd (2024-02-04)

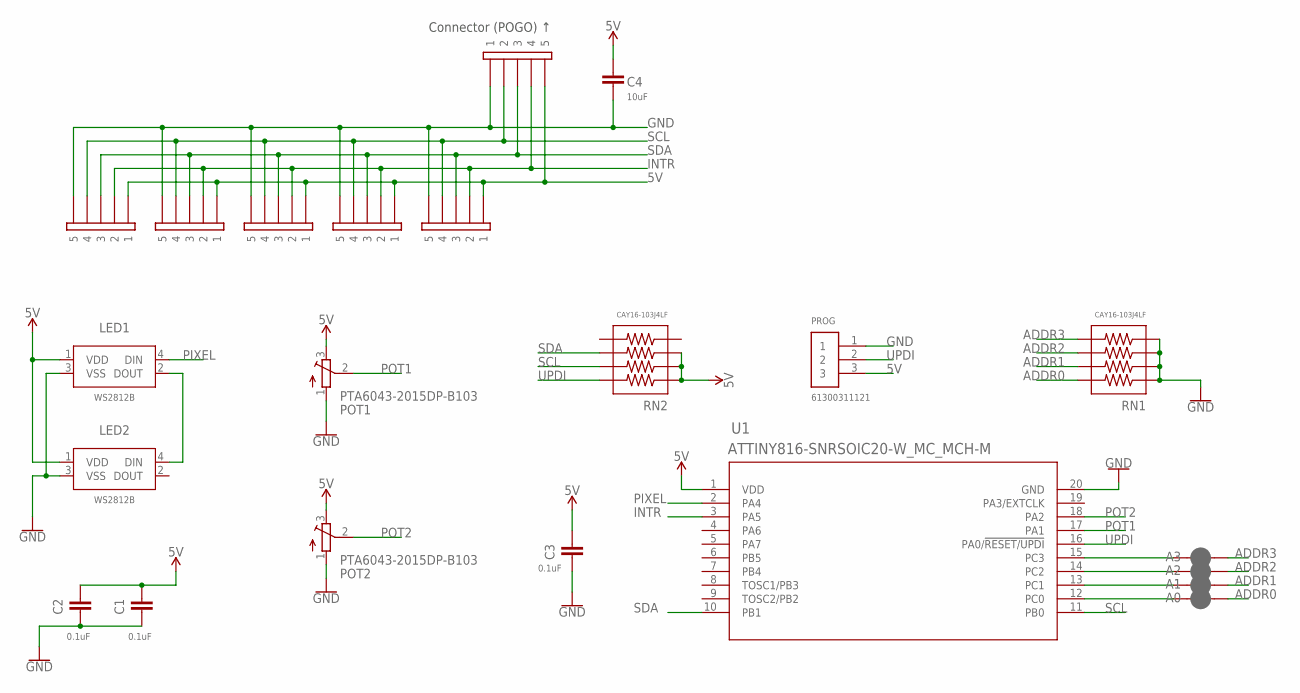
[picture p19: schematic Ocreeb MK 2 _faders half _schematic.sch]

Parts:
A0, A1, A2, A3: JUMPER-SMT_2_NC_PASTE_SILK; SMT-JUMPER_2_NC_PASTE_SILK
C1, C2, C3: 0.1uF; CAPC1608X85
C4: 10uF; CAPC2012X110
LED1, LED2: WS2812B
POT1, POT2: PTA6043-2015DP-B103
PROG: 61300311121
RN1, RN2: CAY16-103J4LF; RESCAF80P320X160X60-8N
U1: ATTINY816-SNRSOIC20-W_MC_MCH-M; SOIC20-W_MC_MCH-M
U$1: 5PIN_EDGE5_POGO_EDGE_OUT_; 5_POGO_EDGE
U$2, U$3, U$4, U$5, U$6: 5PIN_EDGE; 5_POGO_EDGE

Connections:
5V: C1.2, C2.2, C3.2, C4.2, LED1.1 (VDD), LED2.1 (VDD), POT1.3, POT2.3, PROG.3, RN2.1, RN2.2, RN2.3, U1.1 (VDD), U$1.5, U$2.1, U$3.1, U$4.1, U$5.1, U$6.1
ADDR0: A0.1, RN1.8
ADDR1: A1.1, RN1.7
ADDR2: A2.1, RN1.6
ADDR3: A3.1, RN1.5
GND: C1.1, C2.1, C3.1, C4.1, LED1.3 (VSS), LED2.3 (VSS), POT1.1, POT2.1, PROG.1, RN1.1, RN1.2, RN1.3, RN1.4, U1.20 (GND), U$1.1, U$2.5, U$3.5, U$4.5, U$5.5, U$6.5
INTR: U1.3 (PA5), U$1.4, U$2.2, U$3.2, U$4.2, U$5.2, U$6.2
unnamed: LED1.2 (DOUT), LED2.4 (DIN)
unnamed: A3.2, U1.15 (PC3)
unnamed: A2.2, U1.14 (PC2)
unnamed: A1.2, U1.13 (PC1)
unnamed: A0.2, U1.12 (PC0)
PIXEL: LED1.4 (DIN), U1.2 (PA4)
POT1: POT1.2, U1.17 (PA1)
POT2: POT2.2, U1.18 (PA2)
SCL: RN2.7, U1.11 (PB0), U$1.2, U$2.4, U$3.4, U$4.4, U$5.4, U$6.4
SDA: RN2.6, U1.10 (PB1), U$1.3, U$2.3, U$3.3, U$4.3, U$5.3, U$6.3
UPDI: PROG.2, RN2.8, U1.16 (PA0/!RESET/UPDI)

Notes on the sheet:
Connector (POGO) ↑

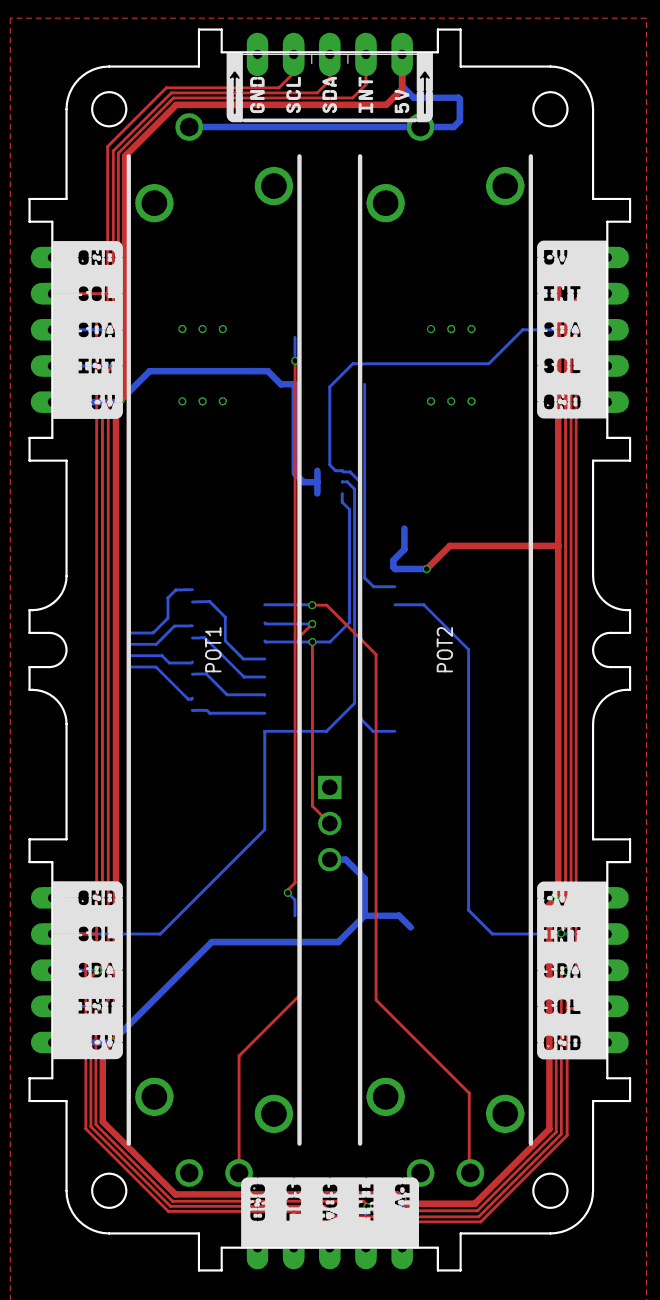
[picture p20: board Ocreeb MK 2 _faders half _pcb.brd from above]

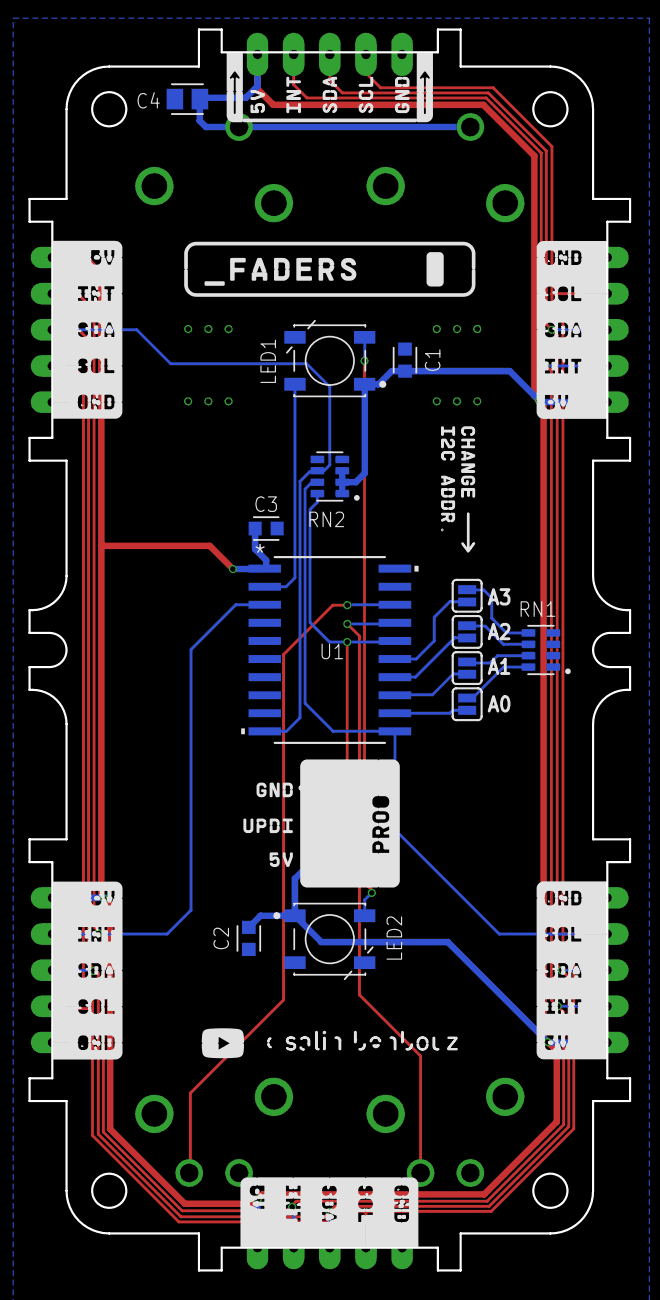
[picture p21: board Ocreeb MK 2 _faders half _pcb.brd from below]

Board: 2 copper layers, 42.2 x 87.2 mm, 22 parts (14 on the bottom side), 18 nets.

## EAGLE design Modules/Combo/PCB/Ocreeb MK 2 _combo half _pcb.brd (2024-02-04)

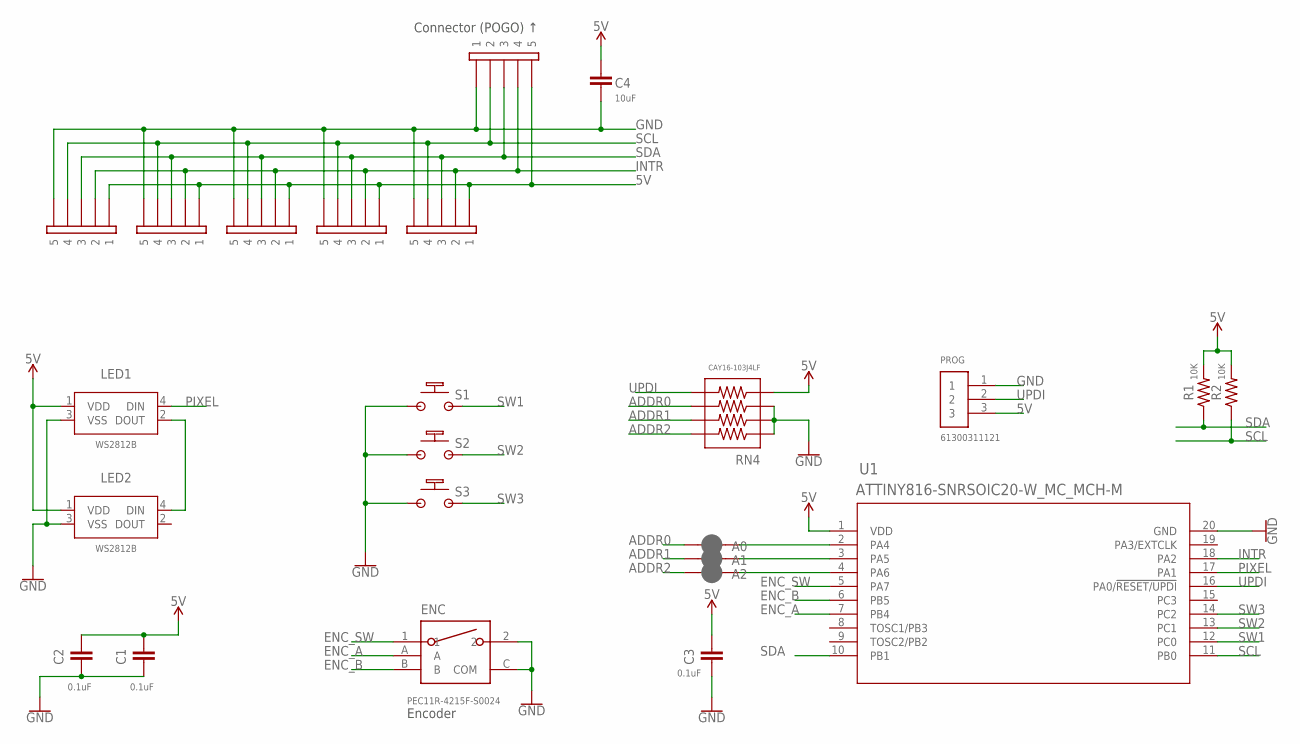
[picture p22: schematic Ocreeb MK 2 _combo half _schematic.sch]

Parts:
A0, A1, A2: JUMPER-SMT_2_NC_PASTE_SILK; SMT-JUMPER_2_NC_PASTE_SILK
C1, C2, C3: 0.1uF; CAPC1608X85
C4: 10uF; CAPC2012X110
ENC: PEC11R-4215F-S0024
LED1, LED2: WS2812B
PROG: 61300311121
R1, R2: 10K; RESC1608X60
RN4: CAY16-103J4LF; RESCAF80P320X160X60-8N
S1, S2, S3: MX1A-11NNCHERRY_MX_SOLDER; CHERRY_MX1A-11NN_SWITCH_NO_HOTSWAP
U1: ATTINY816-SNRSOIC20-W_MC_MCH-M; SOIC20-W_MC_MCH-M
U$1: 5PIN_EDGE5_POGO_EDGE_OUT_; 5_POGO_EDGE
U$2, U$3, U$4, U$5, U$6: 5PIN_EDGE; 5_POGO_EDGE

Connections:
5V: C1.2, C2.2, C3.2, C4.2, LED1.1 (VDD), LED2.1 (VDD), PROG.3, R1.2, R2.2, RN4.4, U1.1 (VDD), U$1.5, U$2.1, U$3.1, U$4.1, U$5.1, U$6.1
ADDR0: A0.1, RN4.6
ADDR1: A1.1, RN4.7
ADDR2: A2.1, RN4.8
ENC_A: ENC.A, U1.7 (PB4)
ENC_B: ENC.B, U1.6 (PB5)
ENC_SW: ENC.1, U1.5 (PA7)
GND: C1.1, C2.1, C3.1, C4.1, ENC.2, ENC.C (COM), LED1.3 (VSS), LED2.3 (VSS), PROG.1, RN4.1, RN4.2, RN4.3, S1.1_ALT (1), S2.1_ALT (1), S3.1_ALT (1), U1.20 (GND), U$1.1, U$2.5, U$3.5, U$4.5, U$5.5, U$6.5
INTR: U1.18 (PA2), U$1.4, U$2.2, U$3.2, U$4.2, U$5.2, U$6.2
unnamed: LED1.2 (DOUT), LED2.4 (DIN)
unnamed: A0.2, U1.2 (PA4)
unnamed: A1.2, U1.3 (PA5)
unnamed: A2.2, U1.4 (PA6)
PIXEL: LED1.4 (DIN), U1.17 (PA1)
SCL: R2.1, U1.11 (PB0), U$1.2, U$2.4, U$3.4, U$4.4, U$5.4, U$6.4
SDA: R1.1, U1.10 (PB1), U$1.3, U$2.3, U$3.3, U$4.3, U$5.3, U$6.3
SW1: S1.2_ALT (2), U1.12 (PC0)
SW2: S2.2_ALT (2), U1.13 (PC1)
SW3: S3.2_ALT (2), U1.14 (PC2)
UPDI: PROG.2, RN4.5, U1.16 (PA0/!RESET/UPDI)

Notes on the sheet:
Encoder
Connector (POGO) ↑

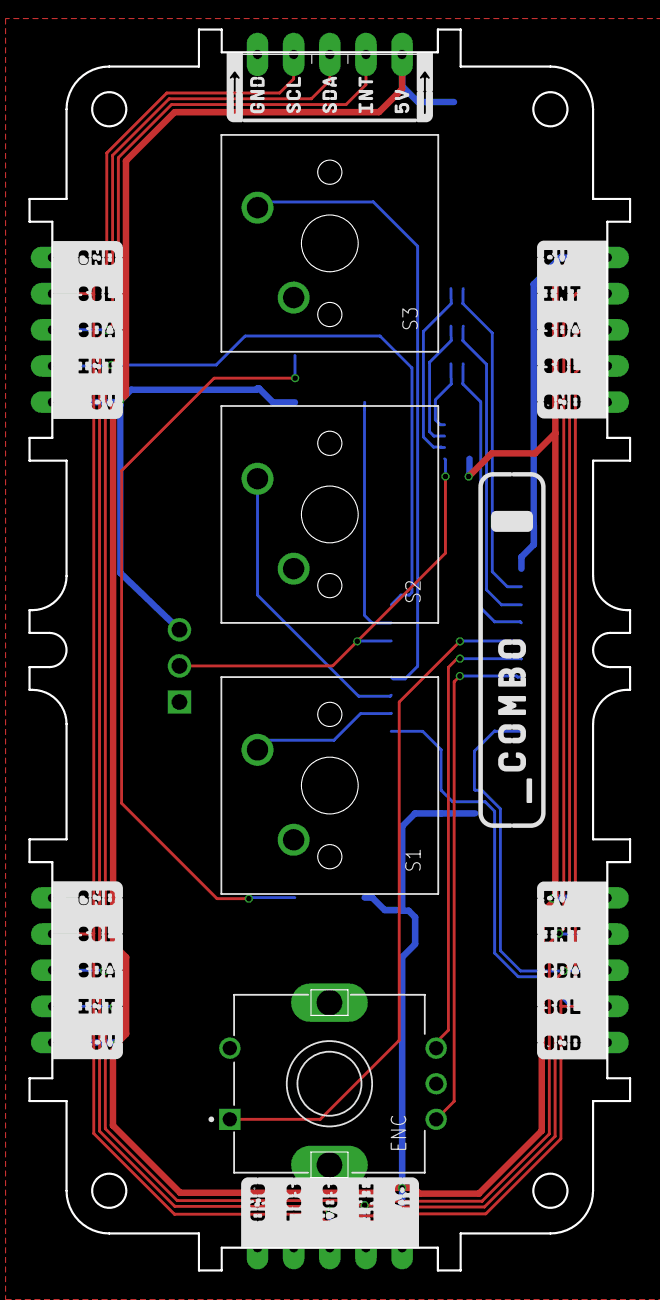
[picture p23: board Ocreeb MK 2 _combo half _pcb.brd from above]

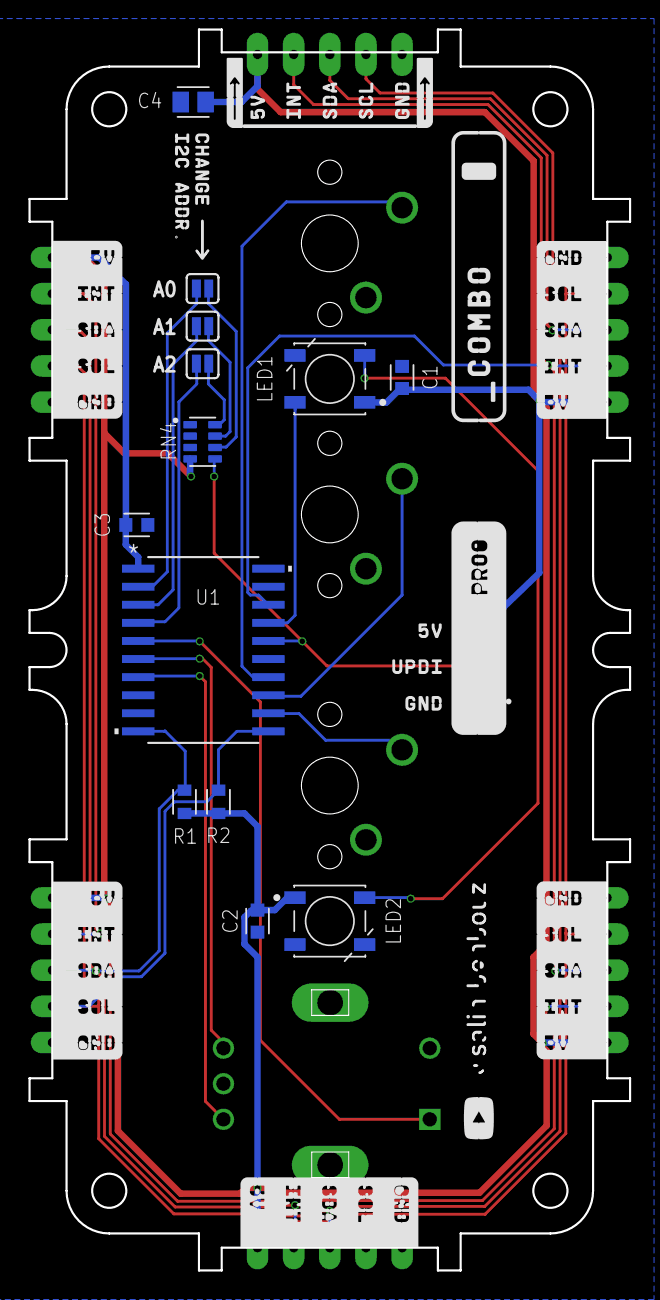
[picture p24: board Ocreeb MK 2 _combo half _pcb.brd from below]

Board: 2 copper layers, 42.2 x 87.2 mm, 24 parts (14 on the bottom side), 20 nets.

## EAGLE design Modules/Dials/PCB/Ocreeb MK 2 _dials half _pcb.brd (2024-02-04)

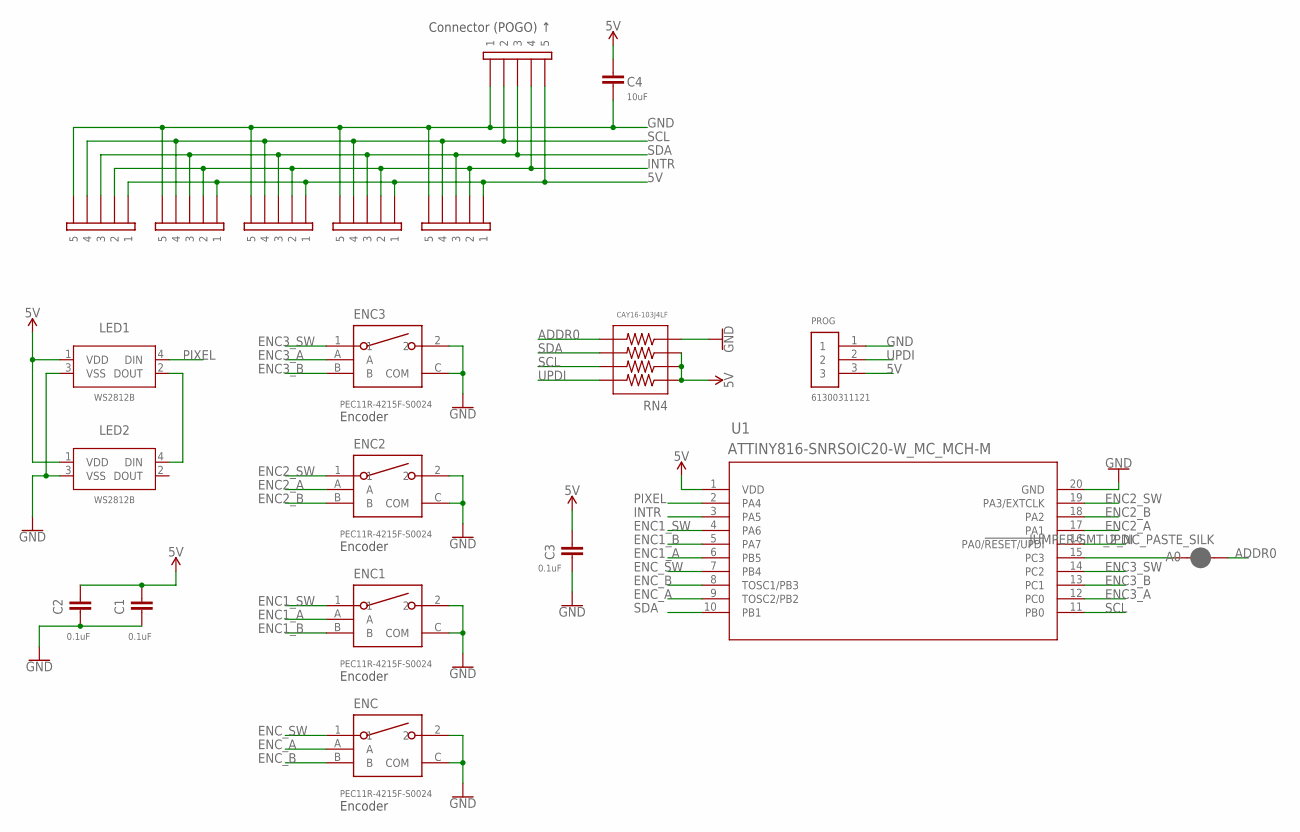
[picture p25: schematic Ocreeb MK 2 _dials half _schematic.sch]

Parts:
A0: JUMPER-SMT_2_NC_PASTE_SILK; SMT-JUMPER_2_NC_PASTE_SILK
C1, C2, C3: 0.1uF; CAPC1608X85
C4: 10uF; CAPC2012X110
ENC, ENC1, ENC2, ENC3: PEC11R-4215F-S0024
LED1, LED2: WS2812B
PROG: 61300311121
RN4: CAY16-103J4LF; RESCAF80P320X160X60-8N
U1: ATTINY816-SNRSOIC20-W_MC_MCH-M; SOIC20-W_MC_MCH-M
U$1: 5PIN_EDGE5_POGO_EDGE_OUT_; 5_POGO_EDGE
U$2, U$3, U$4, U$5, U$6: 5PIN_EDGE; 5_POGO_EDGE

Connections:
5V: C1.2, C2.2, C3.2, C4.2, LED1.1 (VDD), LED2.1 (VDD), PROG.3, RN4.1, RN4.2, RN4.3, U1.1 (VDD), U$1.5, U$2.1, U$3.1, U$4.1, U$5.1, U$6.1
ADDR0: A0.1, RN4.5
ENC1_A: ENC1.A, U1.6 (PB5)
ENC1_B: ENC1.B, U1.5 (PA7)
ENC1_SW: ENC1.1, U1.4 (PA6)
ENC2_A: ENC2.A, U1.17 (PA1)
ENC2_B: ENC2.B, U1.18 (PA2)
ENC2_SW: ENC2.1, U1.19 (PA3/EXTCLK)
ENC3_A: ENC3.A, U1.12 (PC0)
ENC3_B: ENC3.B, U1.13 (PC1)
ENC3_SW: ENC3.1, U1.14 (PC2)
ENC_A: ENC.A, U1.9 (TOSC2/PB2)
ENC_B: ENC.B, U1.8 (TOSC1/PB3)
ENC_SW: ENC.1, U1.7 (PB4)
GND: C1.1, C2.1, C3.1, C4.1, ENC.2, ENC.C (COM), ENC1.2, ENC1.C (COM), ENC2.2, ENC2.C (COM), ENC3.2, ENC3.C (COM), LED1.3 (VSS), LED2.3 (VSS), PROG.1, RN4.4, U1.20 (GND), U$1.1, U$2.5, U$3.5, U$4.5, U$5.5, U$6.5
INTR: U1.3 (PA5), U$1.4, U$2.2, U$3.2, U$4.2, U$5.2, U$6.2
unnamed: LED1.2 (DOUT), LED2.4 (DIN)
unnamed: A0.2, U1.15 (PC3)
PIXEL: LED1.4 (DIN), U1.2 (PA4)
SCL: RN4.7, U1.11 (PB0), U$1.2, U$2.4, U$3.4, U$4.4, U$5.4, U$6.4
SDA: RN4.6, U1.10 (PB1), U$1.3, U$2.3, U$3.3, U$4.3, U$5.3, U$6.3
UPDI: PROG.2, RN4.8, U1.16 (PA0/!RESET/UPDI)

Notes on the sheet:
Encoder
Connector (POGO) ↑

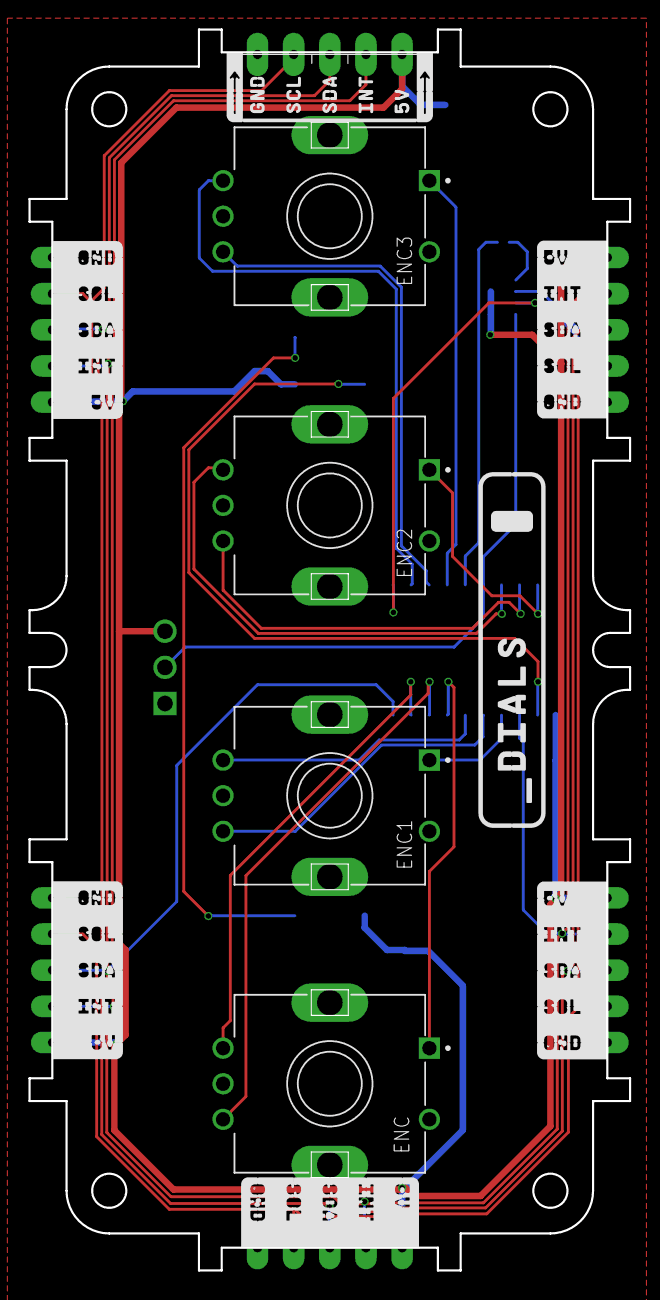
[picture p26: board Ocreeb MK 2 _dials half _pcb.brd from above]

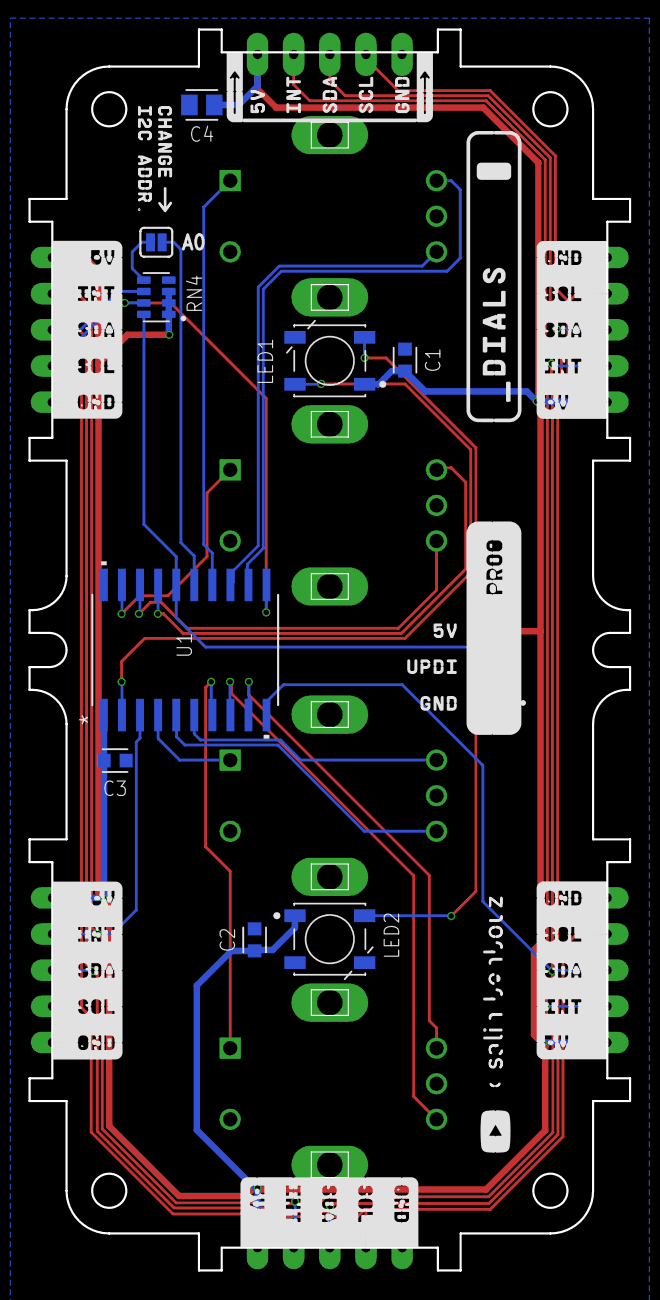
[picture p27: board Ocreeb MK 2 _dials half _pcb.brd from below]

Board: 2 copper layers, 42.2 x 87.2 mm, 20 parts (10 on the bottom side), 22 nets.

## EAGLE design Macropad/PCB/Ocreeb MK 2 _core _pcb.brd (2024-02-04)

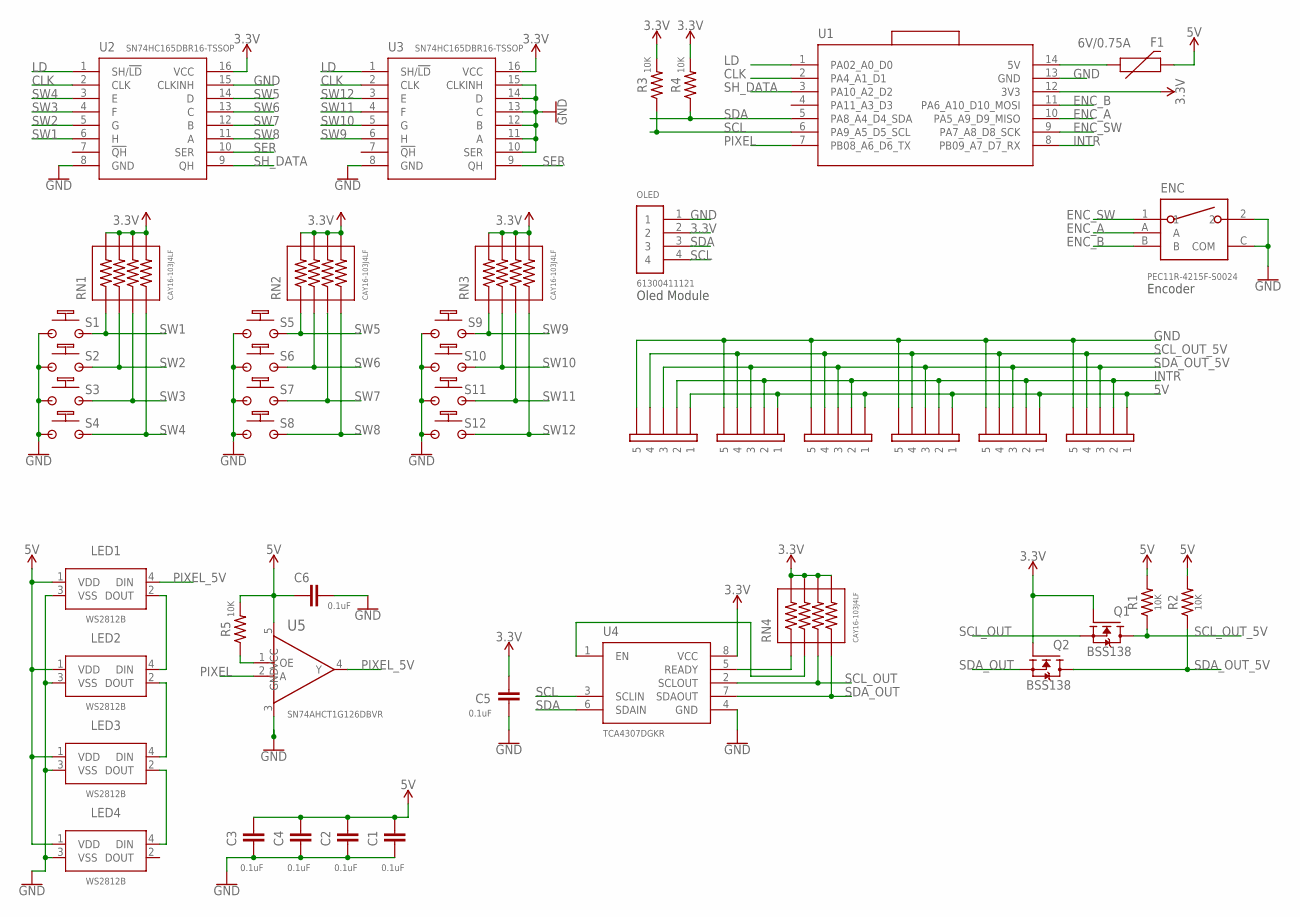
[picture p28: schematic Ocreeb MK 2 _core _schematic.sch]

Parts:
C1, C2, C3, C4, C5, C6: 0.1uF; CAPC1608X85
ENC: PEC11R-4215F-S0024
F1: 6V/0.75A; 1206
LED1, LED2, LED3, LED4: WS2812B
OLED: 61300411121
Q1, Q2: BSS138; SOT95P240X111-3N
R1, R2, R3, R4, R5: 10K; RESC1608X60
RN1, RN2, RN3, RN4: CAY16-103J4LF; RESCAF80P320X160X60-8N
S1, S2, S3, S4, S5, S6, S7, S8, S9, S10, S11, S12: MX1A-11NN; CHERRY_MX1A-11NN_SWITCH
U1: MOUDLE-SEEEDUINO-XIAO-SMD; MOUDLE14P-SMD-2.54-21X17.8MM
U2, U3: SN74HC165DBR16-TSSOP; SOP65P640X120-16N
U4: TCA4307DGKR; SOP65P490X110-8N
U5: SN74AHCT1G126DBVR; SOT95P280X145-5N
U$1, U$2, U$3, U$4, U$5, U$6: 5PIN_EDGE; 5_POGO_EDGE

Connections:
3.3V: C5.2, OLED.2, Q1.1 (G), Q2.1 (G), R3.2, R4.2, RN1.5, RN1.6, RN1.7, RN1.8, RN2.5, RN2.6, RN2.7, RN2.8, RN3.5, RN3.6, RN3.7, RN3.8, RN4.5, RN4.6, RN4.7, RN4.8, U1.12 (3V3), U2.16 (VCC), U3.16 (VCC), U4.8 (VCC)
5V: C1.2, C2.2, C3.2, C4.2, C6.2, F1.2, LED1.1 (VDD), LED2.1 (VDD), LED3.1 (VDD), LED4.1 (VDD), R1.2, R2.2, R5.2, U5.5 (VCC), U$1.1, U$2.1, U$3.1, U$4.1, U$5.1, U$6.1
CLK: U1.2 (PA4_A1_D1), U2.2 (CLK), U3.2 (CLK)
ENC_A: ENC.A, U1.10 (PA5_A9_D9_MISO)
ENC_B: ENC.B, U1.11 (PA6_A10_D10_MOSI)
ENC_SW: ENC.1, U1.9 (PA7_A8_D8_SCK)
GND: C1.1, C2.1, C3.1, C4.1, C5.1, C6.1, ENC.2, ENC.C (COM), LED1.3 (VSS), LED2.3 (VSS), LED3.3 (VSS), LED4.3 (VSS), OLED.1, S1.1, S1.1_ALT (1), S2.1, S2.1_ALT (1), S3.1, S3.1_ALT (1), S4.1, S4.1_ALT (1), S5.1, S5.1_ALT (1), S6.1, S6.1_ALT (1), S7.1, S7.1_ALT (1), S8.1, S8.1_ALT (1), S9.1, S9.1_ALT (1), S10.1, S10.1_ALT (1), S11.1, S11.1_ALT (1), S12.1, S12.1_ALT (1), U1.13 (GND), U2.8 (GND), U2.15 (CLKINH), U3.8 (GND), U3.10 (SER), U3.11 (A), U3.12 (B), U3.13 (C), U3.14 (D), U3.15 (CLKINH), U4.4 (GND), U5.3 (GND), U$1.5, U$2.5, U$3.5, U$4.5, U$5.5, U$6.5
INTR: U1.8 (PB09_A7_D7_RX), U$1.2, U$2.2, U$3.2, U$4.2, U$5.2, U$6.2
LD: U1.1 (PA02_A0_D0), U2.1 (SH/!LD), U3.1 (SH/!LD)
unnamed: RN4.1, U4.5 (READY)
unnamed: R5.1, U5.1 (OE)
unnamed: LED1.2 (DOUT), LED2.4 (DIN)
unnamed: LED2.2 (DOUT), LED3.4 (DIN)
unnamed: LED3.2 (DOUT), LED4.4 (DIN)
unnamed: RN4.2, U4.1 (EN)
PIXEL: U1.7 (PB08_A6_D6_TX), U5.2 (A)
PIXEL_5V: LED1.4 (DIN), U5.4 (Y)
SCL: OLED.4, R3.1, U1.6 (PA9_A5_D5_SCL), U4.3 (SCLIN)
SCL_OUT: Q1.2 (S), RN4.3, U4.2 (SCLOUT)
SCL_OUT_5V: Q1.3 (D), R1.1, U$1.4, U$2.4, U$3.4, U$4.4, U$5.4, U$6.4
SDA: OLED.3, R4.1, U1.5 (PA8_A4_D4_SDA), U4.6 (SDAIN)
SDA_OUT: Q2.2 (S), RN4.4, U4.7 (SDAOUT)
SDA_OUT_5V: Q2.3 (D), R2.1, U$1.3, U$2.3, U$3.3, U$4.3, U$5.3, U$6.3
SER: U2.10 (SER), U3.9 (QH)
SH_DATA: U1.3 (PA10_A2_D2), U2.9 (QH)
SW1: RN1.1, S1.2, S1.2_ALT (2), U2.6 (H)
SW2: RN1.2, S2.2, S2.2_ALT (2), U2.5 (G)
SW3: RN1.3, S3.2, S3.2_ALT (2), U2.4 (F)
SW4: RN1.4, S4.2, S4.2_ALT (2), U2.3 (E)
SW5: RN2.1, S5.2, S5.2_ALT (2), U2.14 (D)
SW6: RN2.2, S6.2, S6.2_ALT (2), U2.13 (C)
SW7: RN2.3, S7.2, S7.2_ALT (2), U2.12 (B)
SW8: RN2.4, S8.2, S8.2_ALT (2), U2.11 (A)
SW9: RN3.1, S9.2, S9.2_ALT (2), U3.6 (H)
SW10: RN3.2, S10.2, S10.2_ALT (2), U3.5 (G)
SW11: RN3.3, S11.2, S11.2_ALT (2), U3.4 (F)
SW12: RN3.4, S12.2, S12.2_ALT (2), U3.3 (E)
USB_5V: F1.1, U1.14 (5V)

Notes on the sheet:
Oled Module
Encoder

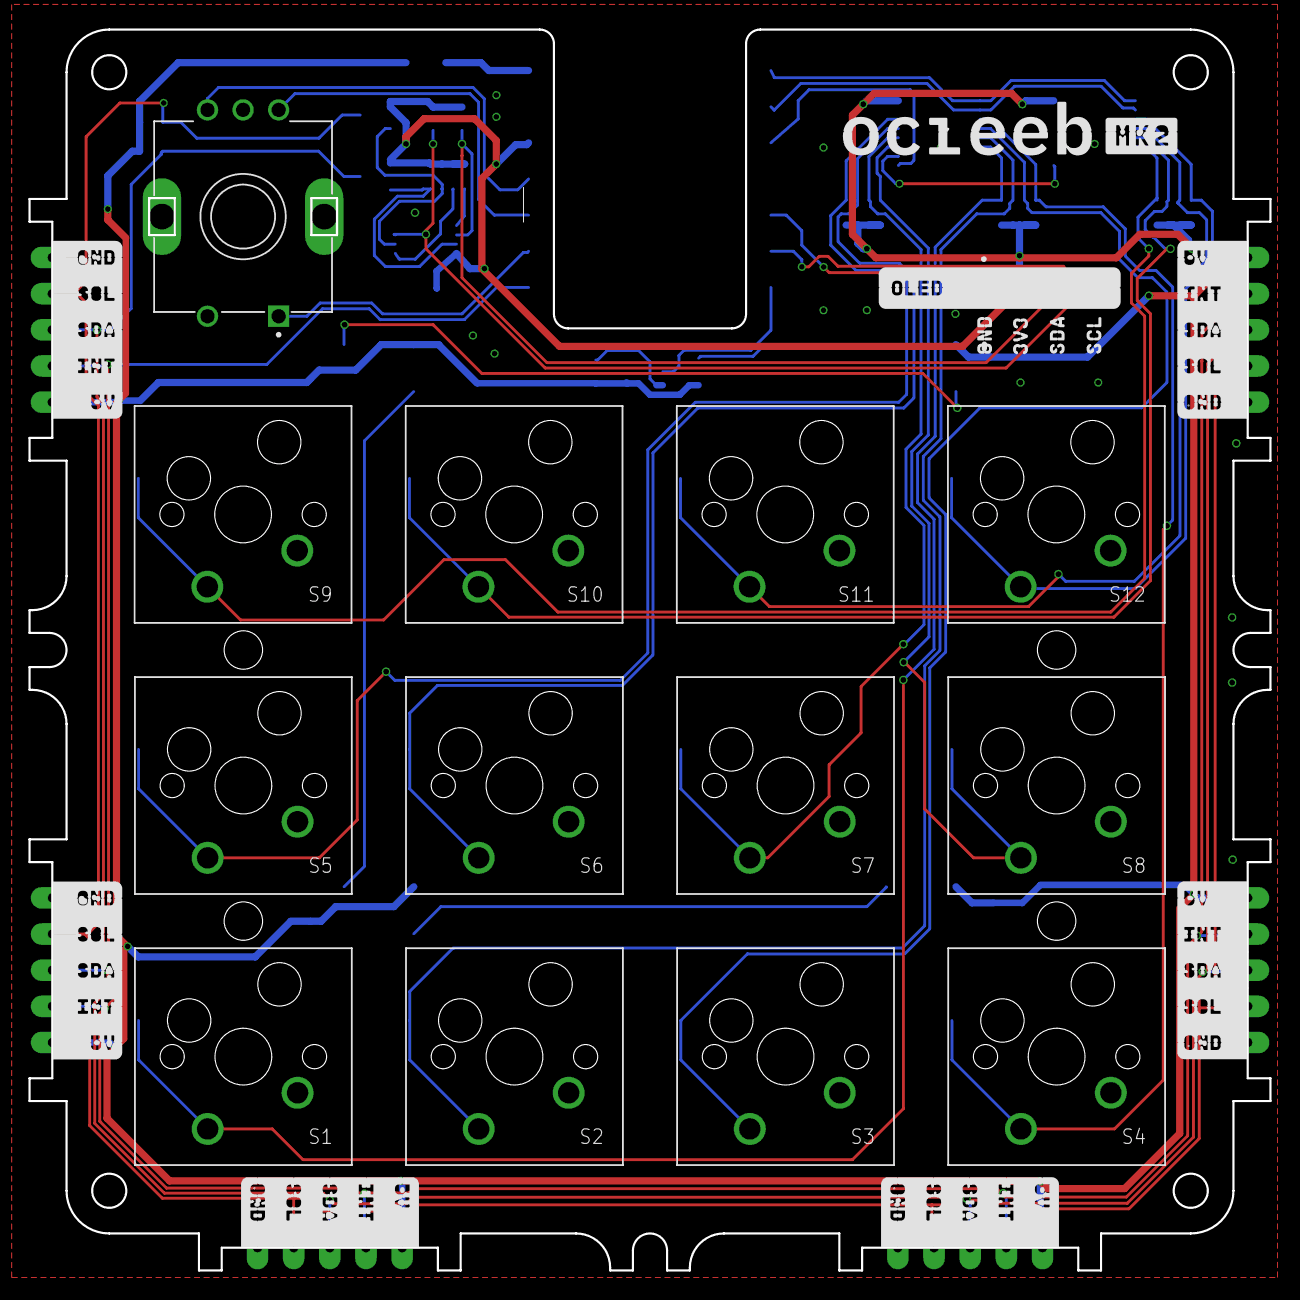
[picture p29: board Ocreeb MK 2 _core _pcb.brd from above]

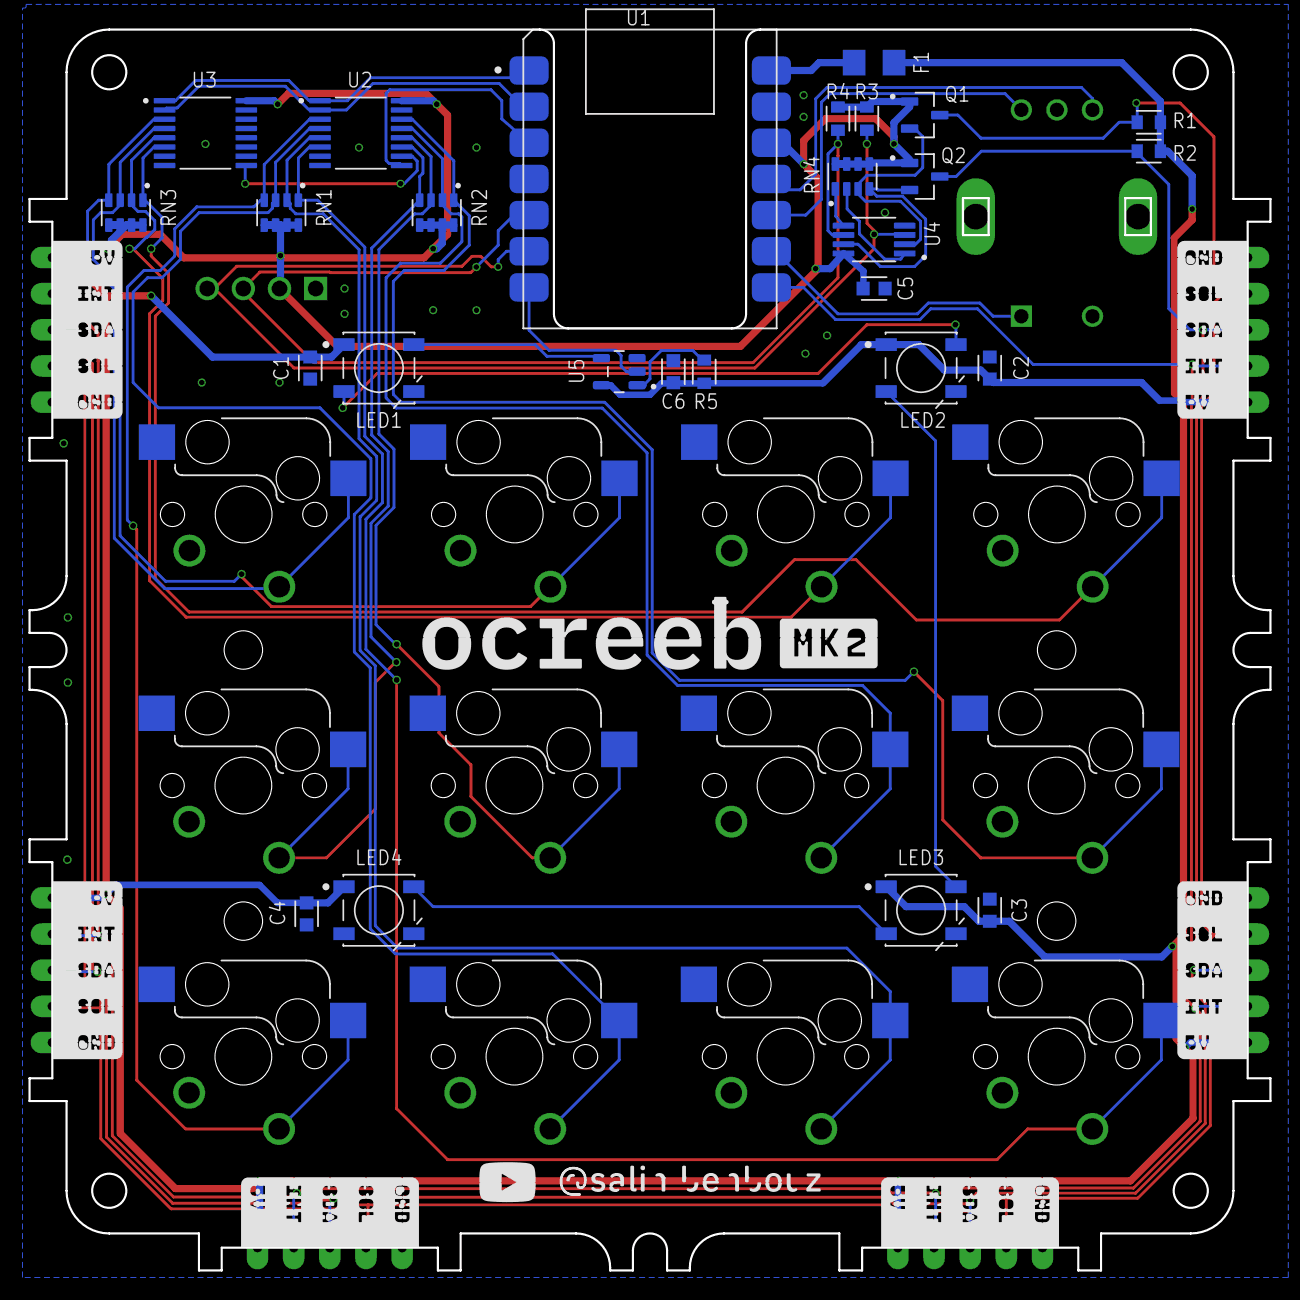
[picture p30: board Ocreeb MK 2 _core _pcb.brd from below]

Board: 2 copper layers, 87.2 x 87.2 mm, 47 parts (27 on the bottom side), 38 nets.

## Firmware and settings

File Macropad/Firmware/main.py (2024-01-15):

print("Ocreeb MK 2 Starting ...")

import board
import busio
import displayio

from kb import OcreebMK2
from kmk.keys import KC
from kmk.modules.layers import Layers
from kmk.modules.encoder import EncoderHandler
from kmk.extensions.media_keys import MediaKeys

from ocreeb.ocreeb_module import ocreebModule

# macropad settings
ocreeb_rgb = True
ocreeb_oled = True
ocreeb_modules = True
layers_names = ['Layer 1', 'Layer 2', 'Layer 3']

displayio.release_displays()
i2c = busio.I2C(scl=board.SCL, sda=board.SDA, frequency=400000)

layers = Layers()
encoder_handler = EncoderHandler()

# init external modules examples depending on the hardware on each one
half_combo = ocreebModule(i2c, addr=0x50, buttons=(10, 11, 12,), num_encoders=1, enc_buttons=(3,), rgb_pin=14, rgb_count=2, rgb_fill=0x008000)
half_faders = ocreebModule(i2c, addr=0x60, analog=(14, 15,), rgb_pin=0, rgb_count=2, rgb_fill=0x008000)
half_dials = ocreebModule(i2c, addr=0x70, num_encoders =4, enc_buttons =(5, 2, 16, 12), rgb_pin=0, rgb_count=2, rgb_fill=0x008000)
full_combo = ocreebModule(i2c, addr=0x52, buttons=(10, 11, 12, 13,), num_encoders=1, rgb_pin=14, rgb_count=4, rgb_fill=0x008000)

# config the main the macropad and pass the external modules
keyboard = OcreebMK2(i2c, layers_names, ocreeb_rgb, ocreeb_oled, ocreeb_modules)
keyboard.modules = [layers, encoder_handler, half_combo, half_dials, half_faders, full_combo]

# this is the encoder on the macropad. Needs to be moved to kb.py
encoder_handler.pins = ((board.D9, board.D10, board.D8,),)

keyboard.extensions.append(MediaKeys())
# keyboard.debug_enabled = True

# ---------------- Main macropad maps ---------------- 
keyboard.keymap = [
    [
        KC.NO,     KC.NO,      KC.NO,      KC.NO,
        KC.NO,     KC.NO,      KC.NO,      KC.NO,
        KC.NO,     KC.NO,      KC.NO,      KC.NO,
    ]   # Layer 1
]

encoder_handler.map = [ 
    (( KC.NO,     KC.NO,      KC.NO),), # Layer 1
    (( KC.NO,     KC.NO,      KC.NO),), # Layer 2
    (( KC.NO,     KC.NO,      KC.NO),), # Layer 3
    ]
# ----------------

# ---------------- Combo module example maps (1 switched encoder, 3 switches) ---------------- 
half_combo.key_map = [
    [ KC.NO,     KC.NO,      KC.NO, ] # Layer 1
]

half_combo.enc_map = [
    (( KC.NO,     KC.NO,      KC.NO),), # Layer 1
    (( KC.NO,     KC.NO,      KC.NO),), # Layer 2
    (( KC.NO,     KC.NO,      KC.NO),), # Layer 3
    ]
# ---------------- 

# ---------------- Dials module example maps (4 switched encoders) ---------------- 
half_dials.enc_map = [
    (( KC.NO,  KC.NO,  KC.NO),   ( KC.NO,  KC.NO,  KC.NO),    ( KC.NO,  KC.NO,  KC.NO),    ( KC.NO,  KC.NO,  KC.NO), ), # Layer 1
    (( KC.NO,  KC.NO,  KC.NO),   ( KC.NO,  KC.NO,  KC.NO),    ( KC.NO,  KC.NO,  KC.NO),    ( KC.NO,  KC.NO,  KC.NO), ), # Layer 2
    (( KC.NO,  KC.NO,  KC.NO),   ( KC.NO,  KC.NO,  KC.NO),    ( KC.NO,  KC.NO,  KC.NO),    ( KC.NO,  KC.NO,  KC.NO), ), # Layer 3
    ]
# ---------------- 

# ---------------- Faders module - example midi notes (2 slider pots) ---------------- 
half_faders.analog_map = [ 40, 60 ]
# ---------------- 

# ---------------- Combo module maps (1 encoder, 4 switches) ---------------- 
full_combo.key_map = [
    [ KC.NO,     KC.NO,     KC.NO,     KC.NO, ] # Layer 1
]

full_combo.enc_map = [
    (( KC.NO,     KC.NO,      KC.NO),), # Layer 1
    (( KC.NO,     KC.NO,      KC.NO),), # Layer 2
    (( KC.NO,     KC.NO,      KC.NO),), # Layer 3
    ]
# ----------------

if __name__ == '__main__':
    keyboard.go()

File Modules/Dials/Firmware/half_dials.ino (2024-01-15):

/* Source: Adafruit's Seesaw Peripheral library. https://github.com/adafruit/Adafruit_seesawPeripheral/tree/main/examples

Modifications:

- Called Adafruit_seesawPeripheral_setIRQ() in setup() to fire the interrupt on first boot.
- Configured UART to use as a first boot flag only.
- Configured pins and I2C addresses for different modules.

Note: To program the modules you need a UPDI Programmer and to complie using megaTinyCore. 
See Adafruit Guide for reprogramming Seesaw with UPDI: https://learn.adafruit.com/adafruit-attiny817-seesaw/advanced-reprogramming-with-updi
*/

#define PRODUCT_CODE            1234
#define CONFIG_I2C_PERIPH_ADDR  0x70

#define CONFIG_INTERRUPT_PIN      1

// Pin to change I2C address on the module
#define CONFIG_ADDR_0_PIN          13
// Used only as a first boot signal by accessing this register and changing the baudrate from the controller side.
#define CONFIG_UART                1
#define CONFIG_UART_BUF_MAX       32
#define CONFIG_UART_SERCOM    Serial
// Other Seesaw features
#define CONFIG_ADC                 1
#define CONFIG_PWM                 1
#define CONFIG_NEOPIXEL            1
#define CONFIG_NEOPIXEL_BUF_MAX   (60*3) // 30 pixels == 180 bytes
// Encoders
#define CONFIG_ENCODER 1
#define CONFIG_NUM_ENCODERS 4
#define CONFIG_ENCODER0_A_PIN 7
#define CONFIG_ENCODER0_B_PIN 6
#define CONFIG_ENCODER1_A_PIN 4
#define CONFIG_ENCODER1_B_PIN 3
#define CONFIG_ENCODER2_A_PIN 14
#define CONFIG_ENCODER2_B_PIN 15
#define CONFIG_ENCODER3_A_PIN 10
#define CONFIG_ENCODER3_B_PIN 11


#include "Adafruit_seesawPeripheral.h"

void setup() { 

  Adafruit_seesawPeripheral_begin();

  // Trigger interrupt on first power up 
  Adafruit_seesawPeripheral_setIRQ();
}


void loop() {
  Adafruit_seesawPeripheral_run();
}

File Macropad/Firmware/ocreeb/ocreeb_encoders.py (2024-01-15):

# ocreeb_encoders.py
from adafruit_seesaw import rotaryio, digitalio
from kmk.modules.encoder import I2CEncoder

class OcreebEncoder(I2CEncoder):
    def __init__(self, seesaw, button_pin, encoder_idx=0, is_inverted=False):
        super(I2CEncoder, self).__init__(is_inverted)
        self.seesaw = seesaw
        self.encoder = rotaryio.IncrementalEncoder(self.seesaw, encoder_idx)
        self.button_pin = button_pin
        
        if self.button_pin:
            self.seesaw.pin_mode(button_pin, self.seesaw.INPUT_PULLUP)
            self.switch = digitalio.DigitalIO(self.seesaw, button_pin)
        
        self._state = self.encoder.position
    
    def button_event(self):
        if not self.button_pin:
            return
        super().button_event()
    
    def get_state(self):
        return {
            'direction': self.is_inverted and -self._direction or self._direction,
            'position': self._state,
            'is_pressed': not self.switch.value if self.button_pin else None,
            'is_held': self._button_held if self.button_pin else None, 
            'velocity': self._velocity,
        }
    
class OcreebEncoders:
    def __init__(self, seesaw, num_encoders, enc_buttons, keyboard, on_move_callback, on_button_callback):
        self.encoders = []
        self.seesaw = seesaw
        self.buttons_mask = self.gpio_mask(enc_buttons) if enc_buttons else None

        for idx in range(num_encoders):
            button_pin = enc_buttons[idx] if idx < len(enc_buttons) else None
            new_encoder = OcreebEncoder(
                seesaw,
                button_pin,
                encoder_idx=idx
            )
            new_encoder.on_move_do = lambda x, bound_idx=idx: on_move_callback(keyboard, bound_idx, x)
            new_encoder.on_button_do = lambda x, bound_idx=idx: on_button_callback(keyboard, bound_idx, x) if button_pin else None

            self.encoders.append(new_encoder)

        self.set_interrupts(num_encoders)

    def set_interrupts(self, num_encoders):
        if self.buttons_mask:
            self.seesaw.pin_mode_bulk(self.buttons_mask, self.seesaw.INPUT_PULLUP)
            self.seesaw.set_GPIO_interrupts(self.buttons_mask, True)
        
        for idx in range(num_encoders):
            self.seesaw.enable_encoder_interrupt(idx)

    def update_encoders(self):
        for encoder in self.encoders:
            encoder.update_state()

    def gpio_mask(self, pins):
        mask = 0
        for pin in pins:
            mask |= 1 << pin
        return mask

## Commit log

2024-01-22 BOMs sup. and Step files
    [Ocreeb MK 2 _combo half _BOM.csv, Ocreeb MK 2 _core _BOM.csv, Ocreeb MK 2 _dials half _BOM.csv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]
2024-02-04 Schematics + keycap STL
    [Ocreeb_keycap.stl]
2024-02-04 Eagle sch + brd files
    [Ocreeb MK 2 _combo half _pcb.brd, Ocreeb MK 2 _combo half _schematic.sch, Ocreeb MK 2 _core _pcb.brd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]

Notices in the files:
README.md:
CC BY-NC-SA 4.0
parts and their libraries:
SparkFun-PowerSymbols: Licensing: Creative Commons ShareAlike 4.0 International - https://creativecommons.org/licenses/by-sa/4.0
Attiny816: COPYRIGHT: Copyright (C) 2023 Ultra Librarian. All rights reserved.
